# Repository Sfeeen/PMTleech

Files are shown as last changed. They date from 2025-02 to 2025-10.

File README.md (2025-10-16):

# 🚀 PMT Leech
#### A Parallel Memory Transactions Monitor

<p align="center">
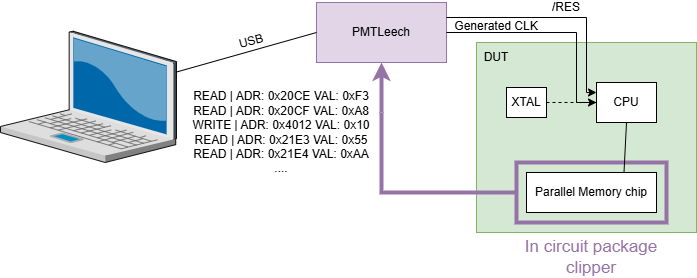
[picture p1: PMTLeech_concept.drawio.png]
PMT Leech Concept PMT Leech PCB
  
</p>

**PMT Leech** is a hardware + software tool that lets you monitor live memory accesses from a CPU to an external parallel memory chip.  
It streams transactions in real-time, while giving you full control over the system clock — allowing **pausing, stepping, and instruction-level debugging**.

---

## 🔧 When Should You Use PMT Leech?

PMT Leech is especially useful when working with **older electronic systems** that meet these two conditions:
- ✅ The system uses a **parallel memory chip** (like SRAM or EPROM)
- ✅ The CPU operates with an **external clock input**

---

## ⚙️ How It Works

By attaching PMT Leech to your memory chip (via clipper) and supplying your own clock signal to the CPU:
- You gain **live streaming** of memory transactions
- You can **pause or step** through firmware execution  
- You can **reverse engineer or debug** embedded firmware in a safe, controlled way

---

## 🧰 Hardware Overview

<p float="left">
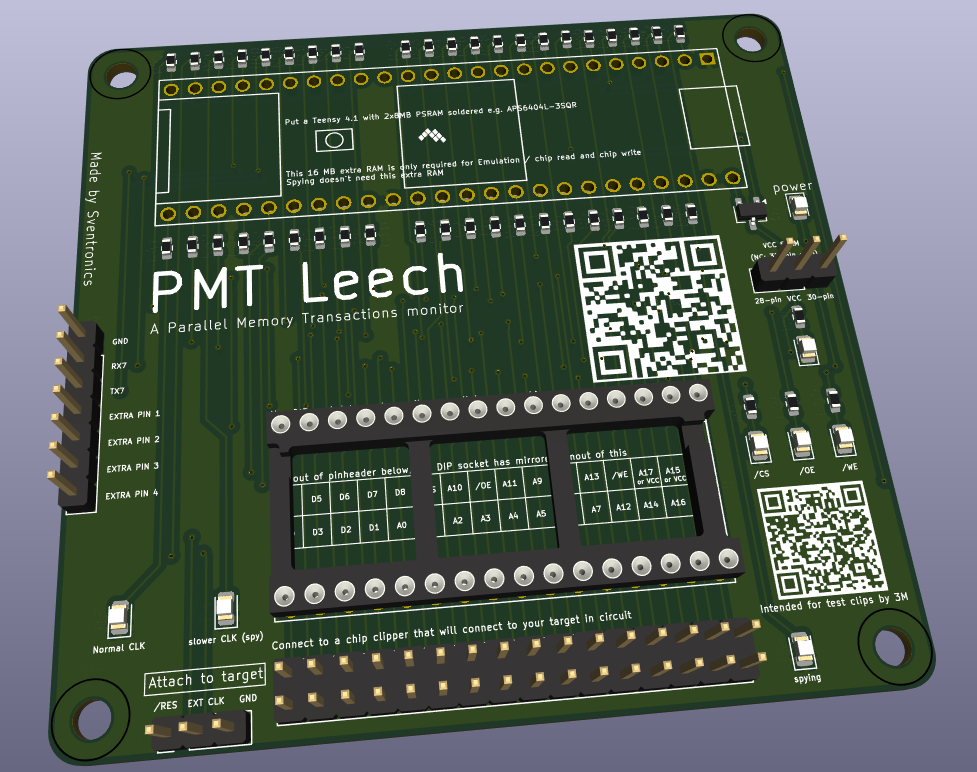
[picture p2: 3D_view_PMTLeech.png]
PMT Leech PCB
  
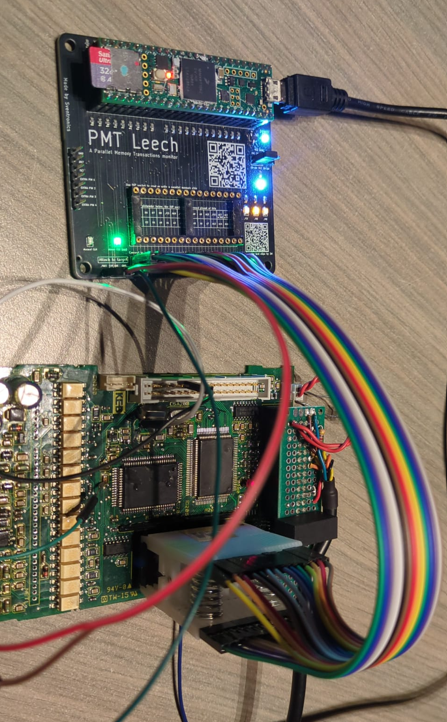
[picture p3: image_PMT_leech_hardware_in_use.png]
PMT Leech In Use In Use
  
</p>

---

## 🖥️ Software Features

<p align="center">
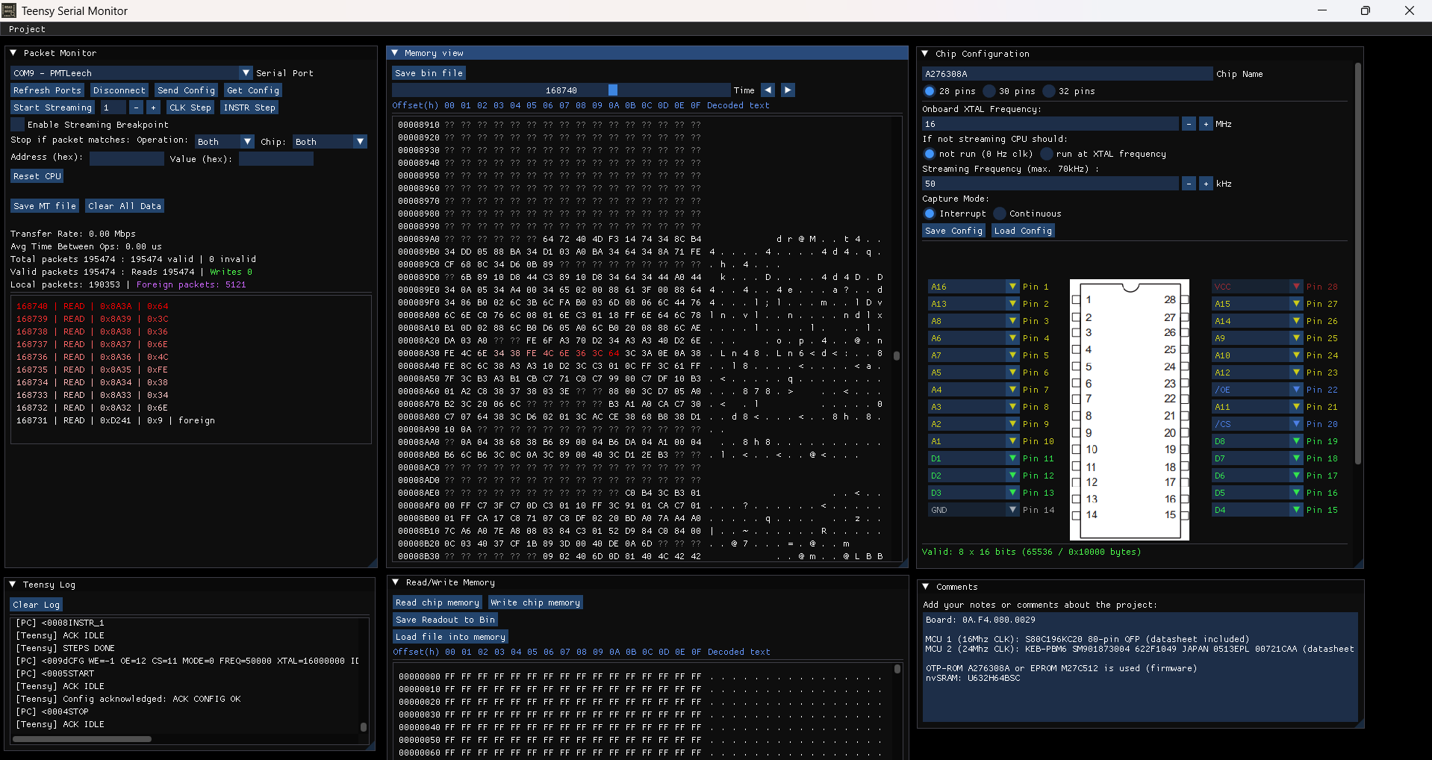
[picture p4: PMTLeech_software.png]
PMT Leech Software Software UI
  
</p>

- 🧩 Configurable pinout: Supports 28, 30, or 32-pin chips
- 📡 Live recording of transactions (up to 70kHz)
- 🎨 Interactive memory viewer with color-coded highlights
- ⏱ Step by **clock** or **instruction**
- 🧠 Detect and label **foreign packets** (from other devices on the memory bus)
- 💾 Off-circuit memory read/write with chip socket

---

## 🎞️ Demo

<p align="center">
  Demo Animation PMT Leech Demo
</p>

---

## 📋 Requirements

### ✅ Memory Chip
- Parallel bus
- ≤ 8-bit data
- ≤ 18 address lines
- 5V compatible (or use 330Ω series resistors)

### ✅ CPU
- Must allow external clock input
- 5V compatible (or 330Ω resistors)

### ⚠️ Note on Timing
The CPU will be **underclocked** (e.g., 8 MHz → 50 kHz). This may affect peripherals like UART:
- Ex: 9600 baud becomes ~60 baud — comms may break.

---

## 🧲 In-Circuit Clip Options

- [📄 3M Test Clip Brochure (PDF)](research/in%20circuit%20connection%20to%20chips/Test%20Clip%20Brochure%203M.pdf)

<p float="left">
  3M Clips
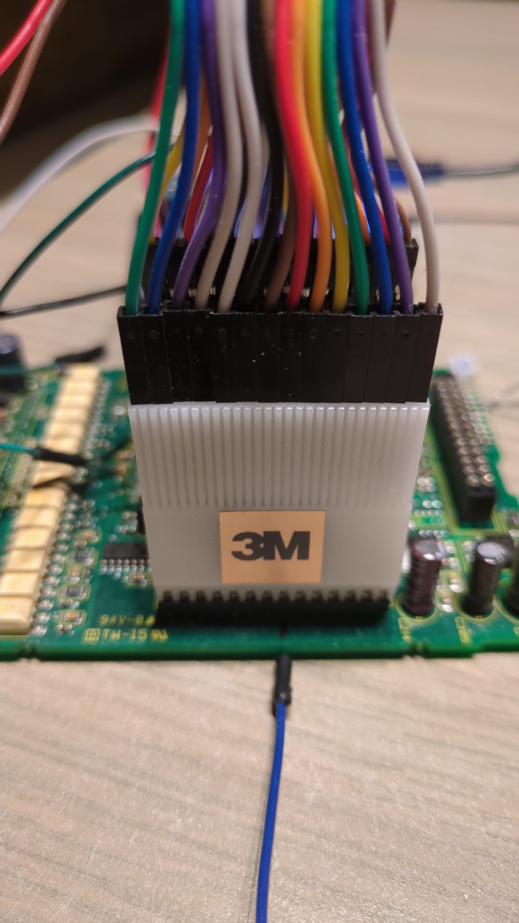
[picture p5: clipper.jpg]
Clipper Photo
  
</p>

---

## 🧠 Supported Memory Types

- EEPROM
- EPROM
- SRAM — **especially valuable** for volatile firmware systems

💡 Many older systems used **SRAM for firmware** due to speed advantages. PMT Leech lets you read these **volatile** setups **without desoldering**.

---

## 🔍 Example Use Cases

- **Bypass password protection**: Record firmware transactions during password validation and discover comparison logic or values.
- **Firmware reverse engineering**: Step through opcode streams and infer instruction flow.
- **Brownout glitching**: Control timing to inject faults and analyze behavior.
  - Related project: [Siemens Advanced Operator Panel](https://github.com/Sfeeen/Siemens-Advanced-Operator-Panel)

---

## 🛠️ Hardware Revisions

### PMT Leech v2 (Current)
<p align="center">
  PMT Leech v2
</p>

### PMT Leech v1 (Development Stage)
<p align="center">
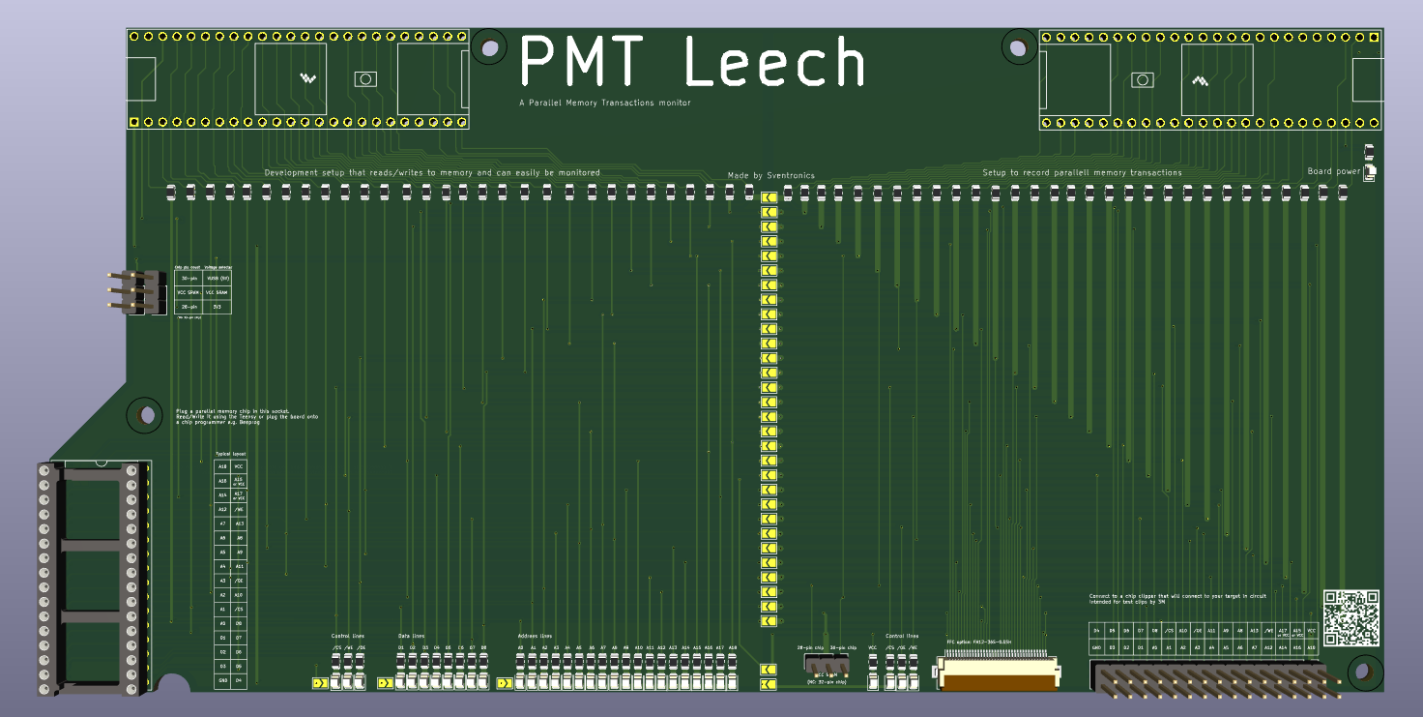
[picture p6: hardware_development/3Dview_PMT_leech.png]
PMT Leech v1
  
</p>

---

##

📧 **Contact**: `svenonderbeke [at] hotmail [dot] com`  
More info to be added soon.

---

### ☕ Support

If you’d like to support the development of PMT Leech, you can donate via Ko-fi:


## 🧪 Version

**Current Version:** `PMT Leech v2`

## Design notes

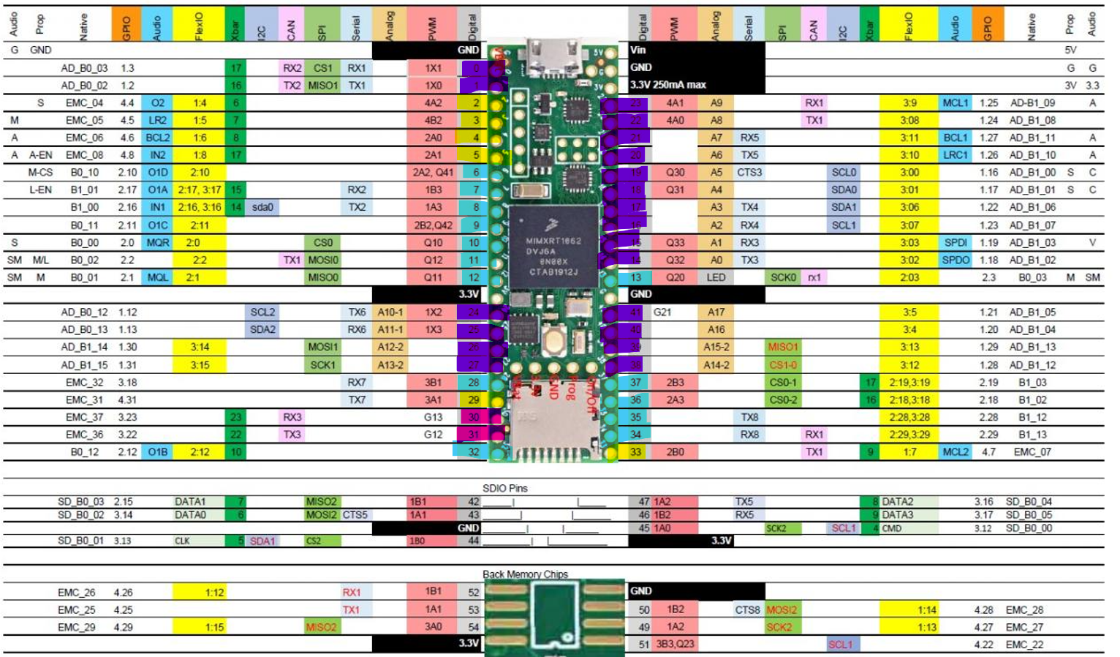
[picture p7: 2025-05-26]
hardware_development/gpio_teensy41_colored.png

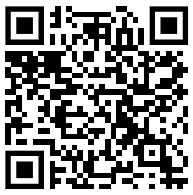
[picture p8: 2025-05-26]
hardware_development/clippers_QR.png

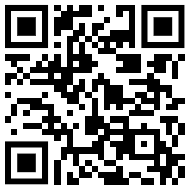
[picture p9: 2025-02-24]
hardware_development/github_PMTleech.png

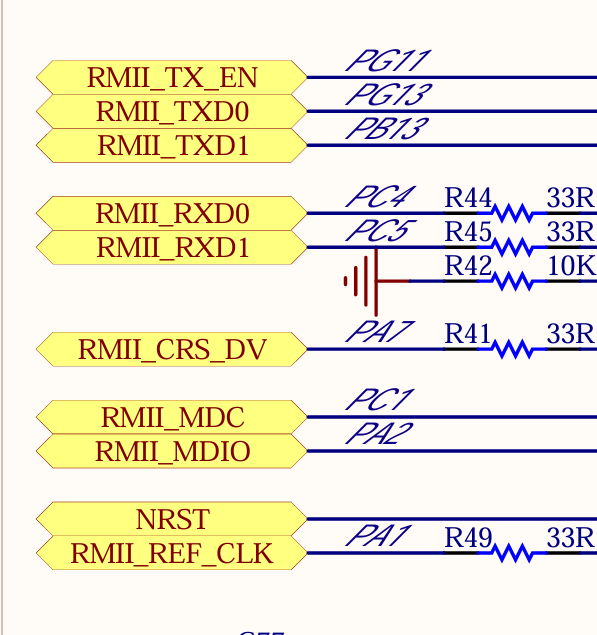
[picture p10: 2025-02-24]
research/stm32 approach w ethernet/nucLEO-H723ZG/RMII_pinout.png

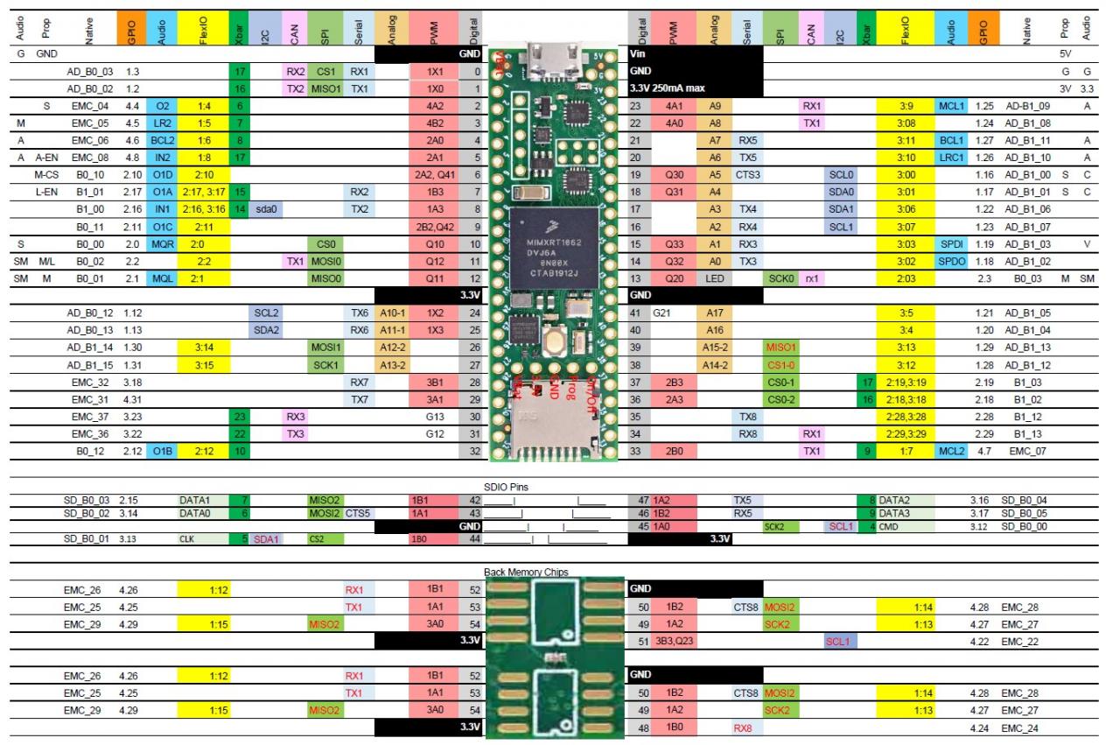
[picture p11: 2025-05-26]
hardware_development/T4.1-Cardlike.jpg

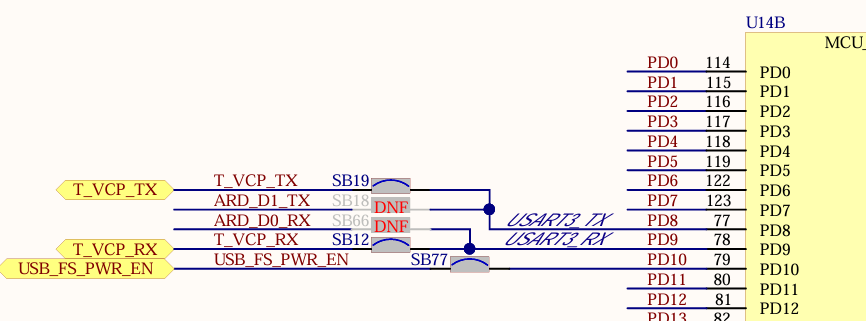
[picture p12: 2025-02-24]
research/stm32 approach w ethernet/nucLEO-H723ZG/USART3.png

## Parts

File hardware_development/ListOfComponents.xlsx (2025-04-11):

Category | Total segment price (€)
Electronic components | 20.96
Electronic units | 59.50
Connectors | 0.00
PCB and casing | 29.19
Mounting | 0.00
Total price | 109.64
Electronic components (ICs, resistors, capacitors, diodes, ...) |  |  |  |  |  |  | Electronic units (Micro-controllers, displays, ...) |  |  |  |  |  |  | Connectors/Large components |  |  |  |  |  |  | PCB and casing |  |  |  |  |  |  | Mounting (Screws, standoffs, spacers, ...)
Component Description | Mfr. Nr | Supplier No. | Supplier | Unit Price | Quantity | Total Price | Component Description | Mfr. Nr | Supplier No. | Supplier | Unit Price | Quantity | Total Price | Component Description | Mfr. Nr | Supplier No. | Supplier | Unit Price | Quantity | Total Price | Component Description | Mfr. Nr | Supplier No. | Supplier | Unit Price | Quantity | Total Price | Component Description | Mfr. Nr | Supplier No. | Supplier | Unit Price | Quantity | Total Price
Total segment price |  |  |  |  |  | 20.96 | Total segment price |  |  |  |  |  | 59.50 | Total segment price |  |  |  |  |  | 0.00 | Total segment price |  |  |  |  |  | 29.19 | Total segment price |  |  |  |  |  | 0.00
TXB0108PWR level shifter | TXB0108PWR | 595-TXB0108PWR | Mouser | 0.89 | 10 | 8.85 | Teensy 4.1 | Teensy 4.1 | 002700 | TINYTRONICS | 29.75 | 2 | 59.50 |  |  |  |  |  |  | 0.00 | PMT Leech PCB 5 stuks | W202502242057287 | W202502242057287 | JLCPCB | 29.19 | 1 | 29.19 |  |  |  |  |  |  | 0.00
330R 0805 weerstand | CRCW0805330RJNEAHP | 71-CRCW0805330RJNEAH | Mouser | 0.04 | 100 | 3.90 |  |  |  |  |  |  | 0.00 |  |  |  |  |  |  | 0.00 |  |  |  |  |  |  | 0.00 |  |  |  |  |  |  | 0.00
LEDS 0805 | 150080BS75000 | 2322075 | Farnell | 0.18 | 35 | 6.47 |  |  |  |  |  |  | 0.00 |  |  |  |  |  |  | 0.00 |  |  |  |  |  |  | 0.00 |  |  |  |  |  |  | 0.00
teensy koelvin | HSB03-121218 | 490-HSB03-121218 | Mouser | 0.86 | 2 | 1.73 |  |  |  |  |  |  | 0.00 |  |  |  |  |  |  | 0.00 |  |  |  |  |  |  | 0.00 |  |  |  |  |  |  | 0.00
IC voet lange poten | t2AJ1401 | t2AJ1401 | esengo |  |  | 0.00 |  |  |  |  |  |  | 0.00 |  |  |  |  |  |  | 0.00 |  |  |  |  |  |  | 0.00 |  |  |  |  |  |  | 0.00
 |  |  |  |  |  | 0.00 |  |  |  |  |  |  | 0.00 |  |  |  |  |  |  | 0.00 |  |  |  |  |  |  | 0.00 |  |  |  |  |  |  | 0.00
 |  |  |  |  |  | 0.00 |  |  |  |  |  |  | 0.00 |  |  |  |  |  |  | 0.00 |  |  |  |  |  |  | 0.00 |  |  |  |  |  |  | 0.00
 |  |  |  |  |  | 0.00 |  |  |  |  |  |  | 0.00 |  |  |  |  |  |  | 0.00 |  |  |  |  |  |  | 0.00 |  |  |  |  |  |  | 0.00
 |  |  |  |  |  | 0.00 |  |  |  |  |  |  | 0.00 |  |  |  |  |  |  | 0.00 |  |  |  |  |  |  | 0.00 |  |  |  |  |  |  | 0.00
 |  |  |  |  |  | 0.00 |  |  |  |  |  |  | 0.00 |  |  |  |  |  |  | 0.00 |  |  |  |  |  |  | 0.00 |  |  |  |  |  |  | 0.00
 |  |  |  |  |  | 0.00 |  |  |  |  |  |  | 0.00 |  |  |  |  |  |  | 0.00 |  |  |  |  |  |  | 0.00 |  |  |  |  |  |  | 0.00
 |  |  |  |  |  | 0.00 |  |  |  |  |  |  | 0.00 |  |  |  |  |  |  | 0.00 |  |  |  |  |  |  | 0.00 |  |  |  |  |  |  | 0.00
 |  |  |  |  |  | 0.00 |  |  |  |  |  |  | 0.00 |  |  |  |  |  |  | 0.00 |  |  |  |  |  |  | 0.00 |  |  |  |  |  |  | 0.00
 |  |  |  |  |  | 0.00 |  |  |  |  |  |  | 0.00 |  |  |  |  |  |  | 0.00 |  |  |  |  |  |  | 0.00 |  |  |  |  |  |  | 0.00
 |  |  |  |  |  | 0.00 |  |  |  |  |  |  | 0.00 |  |  |  |  |  |  | 0.00 |  |  |  |  |  |  | 0.00 |  |  |  |  |  |  | 0.00
 |  |  |  |  |  | 0.00 |  |  |  |  |  |  | 0.00 |  |  |  |  |  |  | 0.00 |  |  |  |  |  |  | 0.00 |  |  |  |  |  |  | 0.00
 |  |  |  |  |  | 0.00 |  |  |  |  |  |  | 0.00 |  |  |  |  |  |  | 0.00 |  |  |  |  |  |  | 0.00 |  |  |  |  |  |  | 0.00
 |  |  |  |  |  | 0.00 |  |  |  |  |  |  | 0.00 |  |  |  |  |  |  | 0.00 |  |  |  |  |  |  | 0.00 |  |  |  |  |  |  | 0.00
 |  |  |  |  |  | 0.00 |  |  |  |  |  |  | 0.00 |  |  |  |  |  |  | 0.00 |  |  |  |  |  |  | 0.00 |  |  |  |  |  |  | 0.00
 |  |  |  |  |  | 0.00 |  |  |  |  |  |  | 0.00 |  |  |  |  |  |  | 0.00 |  |  |  |  |  |  | 0.00 |  |  |  |  |  |  | 0.00
 |  |  |  |  |  | 0.00 |  |  |  |  |  |  | 0.00 |  |  |  |  |  |  | 0.00 |  |  |  |  |  |  | 0.00 |  |  |  |  |  |  | 0.00
 |  |  |  |  |  | 0.00 |  |  |  |  |  |  | 0.00 |  |  |  |  |  |  | 0.00 |  |  |  |  |  |  | 0.00 |  |  |  |  |  |  | 0.00
 |  |  |  |  |  | 0.00 |  |  |  |  |  |  | 0.00 |  |  |  |  |  |  | 0.00 |  |  |  |  |  |  | 0.00 |  |  |  |  |  |  | 0.00
 |  |  |  |  |  | 0.00 |  |  |  |  |  |  | 0.00 |  |  |  |  |  |  | 0.00 |  |  |  |  |  |  | 0.00 |  |  |  |  |  |  | 0.00
 |  |  |  |  |  | 0.00 |  |  |  |  |  |  | 0.00 |  |  |  |  |  |  | 0.00 |  |  |  |  |  |  | 0.00 |  |  |  |  |  |  | 0.00
 |  |  |  |  |  | 0.00 |  |  |  |  |  |  | 0.00 |  |  |  |  |  |  | 0.00 |  |  |  |  |  |  | 0.00 |  |  |  |  |  |  | 0.00
 |  |  |  |  |  | 0.00 |  |  |  |  |  |  | 0.00 |  |  |  |  |  |  | 0.00 |  |  |  |  |  |  | 0.00 |  |  |  |  |  |  | 0.00
 |  |  |  |  |  | 0.00 |  |  |  |  |  |  | 0.00 |  |  |  |  |  |  | 0.00 |  |  |  |  |  |  | 0.00 |  |  |  |  |  |  | 0.00
 |  |  |  |  |  | 0.00 |  |  |  |  |  |  | 0.00 |  |  |  |  |  |  | 0.00 |  |  |  |  |  |  | 0.00 |  |  |  |  |  |  | 0.00
 |  |  |  |  |  | 0.00 |  |  |  |  |  |  | 0.00 |  |  |  |  |  |  | 0.00 |  |  |  |  |  |  | 0.00 |  |  |  |  |  |  | 0.00
 |  |  |  |  |  | 0.00
 |  |  |  |  |  | 0.00
 |  |  |  |  |  | 0.00
 |  |  |  |  |  | 0.00
 |  |  |  |  |  | 0.00
 |  |  |  |  |  | 0.00
 |  |  |  |  |  | 0.00
 |  |  |  |  |  | 0.00
 |  |  |  |  |  | 0.00
 |  |  |  |  |  | 0.00
 |  |  |  |  |  | 0.00
 |  |  |  |  |  | 0.00
 |  |  |  |  |  | 0.00

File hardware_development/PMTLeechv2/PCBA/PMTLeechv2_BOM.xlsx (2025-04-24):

Id | Designator | Footprint | Quantity | Designation | Supplier and ref
1 | R30,R99,R98,R97,R96,R95,R43,R42,R41,R40,R39,R38,R37,R36,R35,R34,R32,R31,R29,R28,R27,R26,R25,R24,R23,R22,R21,R20,R19,R18,R17,R16,R15,R14,R13,R12,R11,R10,R9,R8,R7,R6,R5,R4,R3,R2,R1 | R_0603_1608Metric | 47 | 330R
6 | D34,D35,D33 | LED_0805_2012Metric | 3 | LED
7 | D32,D31 | LED_0805_2012Metric | 2 | LED
8 | D1 | LED_0805_2012Metric | 1 | LED
9 | D2 | LED_0805_2012Metric | 1 | LED
10 | D3 | LED_0805_2012Metric | 1 | LED

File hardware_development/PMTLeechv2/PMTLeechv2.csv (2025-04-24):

Id | Designator | Footprint | Quantity | Designation | Supplier and ref
1 | R30,R99,R98,R97,R96,R95,R43,R42,R41,R40,R39,R38,R37,R36,R35,R34,R32,R31,R29,R28,R27,R26,R25,R24,R23,R22,R21,R20,R19,R18,R17,R16,R15,R14,R13,R12,R11,R10,R9,R8,R7,R6,R5,R4,R3,R2,R1 | R_0603_1608Metric | 47 | 330R
2 | Q2 | TSOT-23 | 1 | Q_PMOS_GSD
3 | J5 | DIP-32_W15.24mm_Socket_LongPads | 1 | Conn_02x16_Counter_Clockwise
4 | J3 | PinHeader_1x07_P2.54mm_Vertical | 1 | Conn_01x07
5 | J1,J2 | PinHeader_1x03_P2.54mm_Vertical | 2 | Conn_01x03
6 | D3,D1,D2,D33,D32,D34,D35,D31 | LED_0805_2012Metric | 8 | LED
7 | U1 | Teensy41 | 1 | Teensy4.1
8 | J8 | PinHeader_2x16_P2.54mm_Vertical_clockwise | 1 | Conn_02x16_Counter_Clockwise

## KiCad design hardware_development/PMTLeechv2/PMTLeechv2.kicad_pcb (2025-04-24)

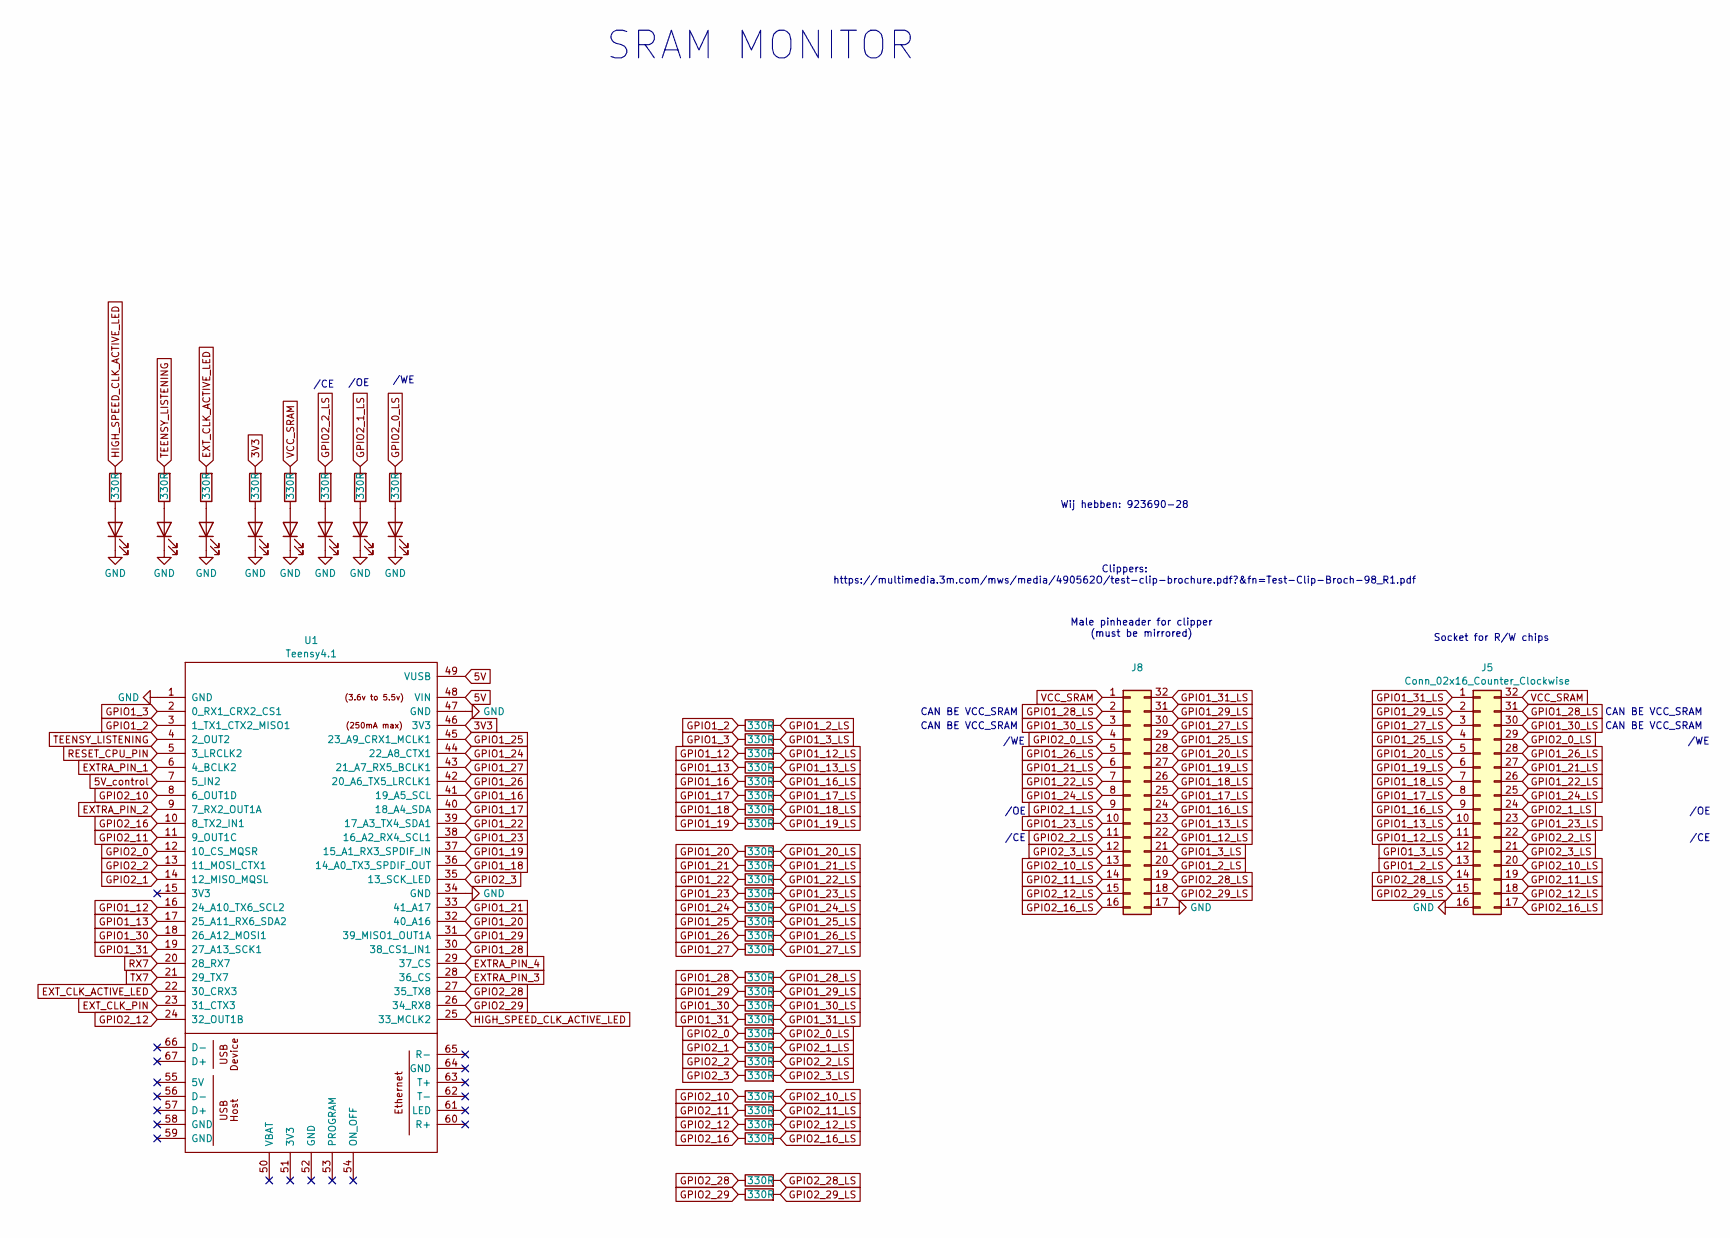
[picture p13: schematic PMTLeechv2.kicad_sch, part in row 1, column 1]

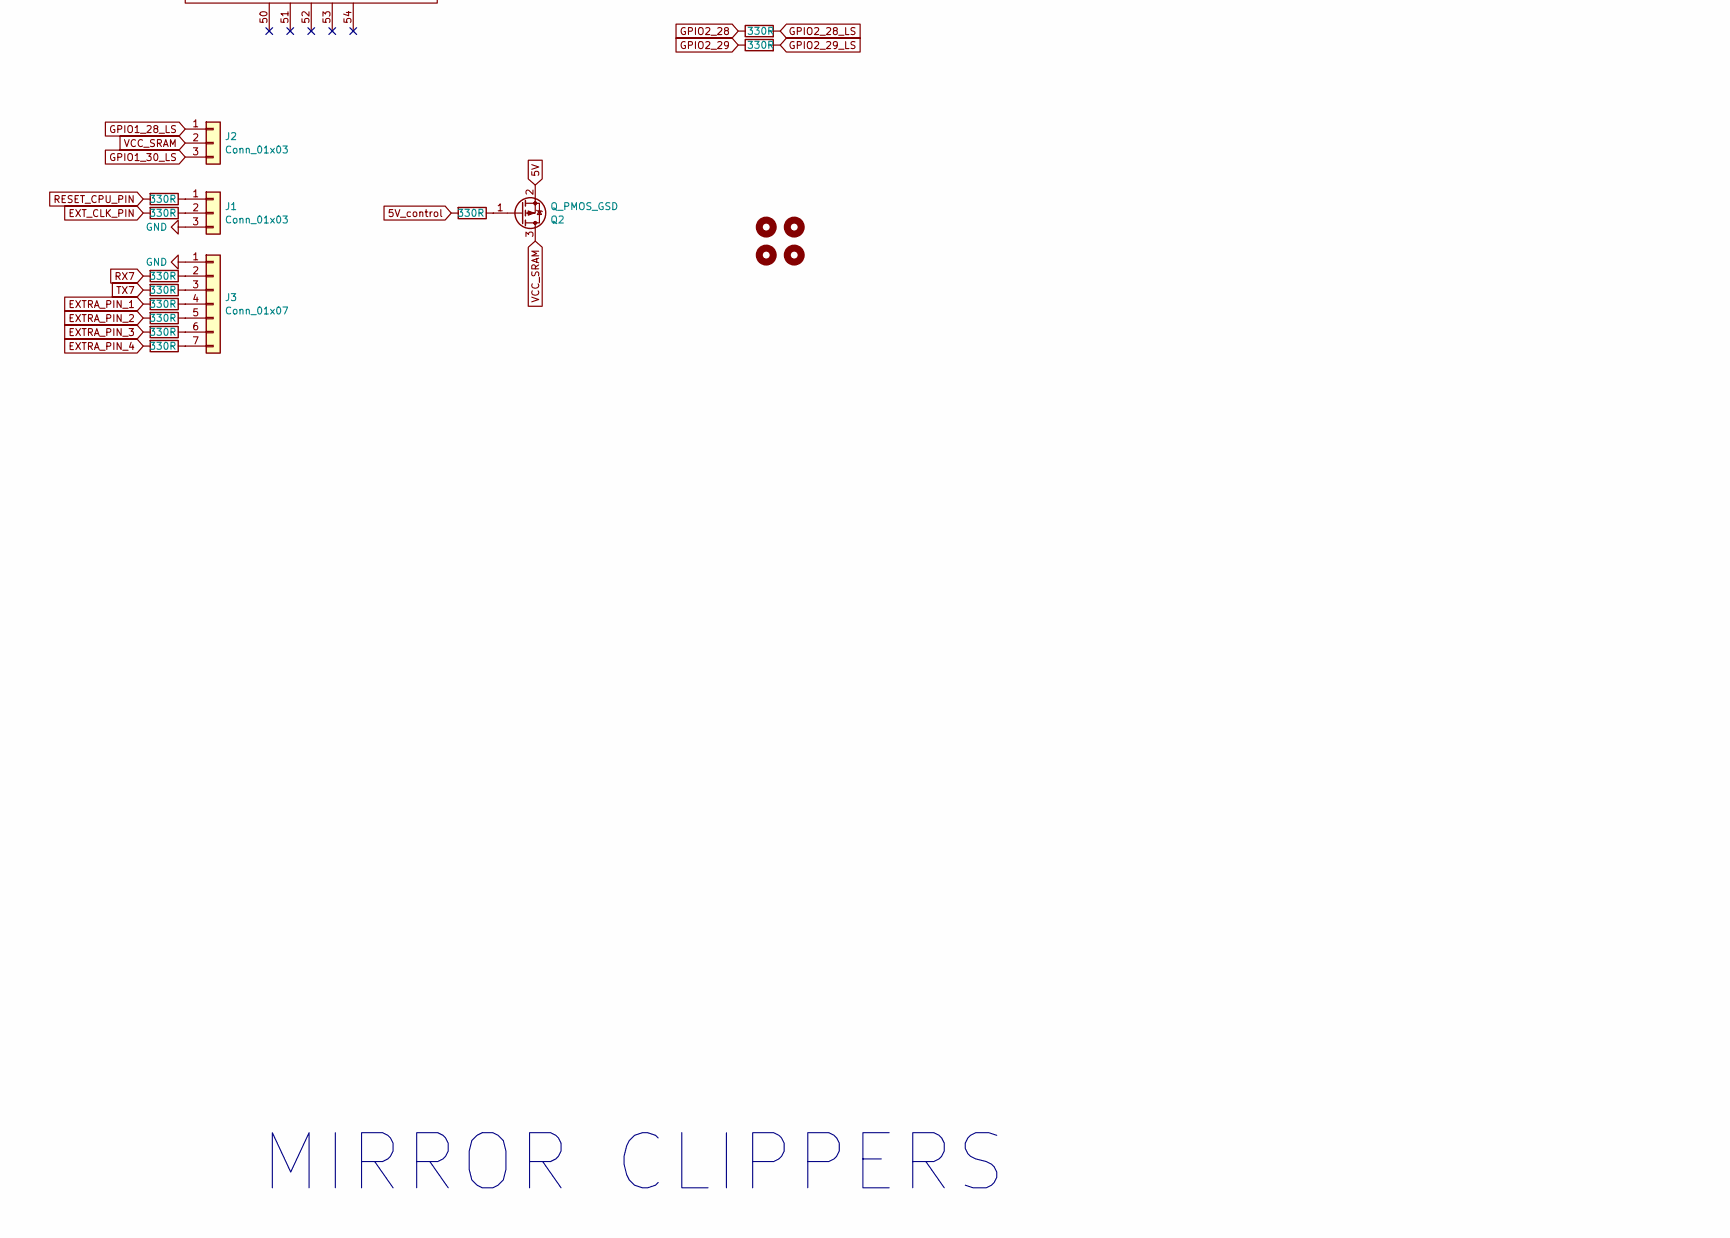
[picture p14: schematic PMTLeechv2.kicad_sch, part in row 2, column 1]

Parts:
D1, D2, D3, D31, D32, D33, D34, D35: LED; LED_0805_2012Metric
H1, H2, H3, H4: MountingHole; MountingHole_3.2mm_M3
J1, J2: Conn_01x03; PinHeader_1x03_P2.54mm_Vertical
J3: Conn_01x07; PinHeader_1x07_P2.54mm_Vertical
J5: Conn_02x16_Counter_Clockwise; DIP-32_W15.24mm_Socket_LongPads
J8: Conn_02x16_Counter_Clockwise; PinHeader_2x16_P2.54mm_Vertical_clockwise
Q2: Q_PMOS_GSD; TSOT-23
R1, R2, R3, R4, R5, R6, R7, R8, R9, R10, R11, R12, R13, R14, R15, R16, R17, R18, R19, R20, R21, R22, R23, R24, R25, R26, R27, R28, R29, R30, R31, R32, R34, R35, R36, R37, R38, R39, R40, R41, R42, R43, R95, R96, R97, R98, R99: 330R; R_0603_1608Metric
U1: Teensy4.1; Teensy41

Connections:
3V3: R95.2, U1.46 (3V3)
5V: Q2.2 (S), U1.48 (VIN), U1.49 (VUSB)
5V_control: R30.2, U1.7 (5_IN2)
EXTRA_PIN_1: R37.2, U1.6 (4_BCLK2)
EXTRA_PIN_2: R42.2, U1.9 (7_RX2_OUT1A)
EXTRA_PIN_3: R38.2, U1.28 (36_CS)
EXTRA_PIN_4: R43.2, U1.29 (37_CS)
EXT_CLK_ACTIVE_LED: R34.2, U1.22 (30_CRX3)
EXT_CLK_PIN: R29.2, U1.23 (31_CTX3)
GND: D1.1 (K), D2.1 (K), D3.1 (K), D31.1 (K), D32.1 (K), D33.1 (K), D34.1 (K), D35.1 (K), J1.3, J3.1, J5.16, J8.17, U1.1 (GND), U1.34 (GND), U1.47 (GND)
GPIO1_2: R1.1, U1.3 (1_TX1_CTX2_MISO1)
GPIO1_2_LS: J5.13, J8.20, R1.2
GPIO1_3: R2.1, U1.2 (0_RX1_CRX2_CS1)
GPIO1_3_LS: J5.12, J8.21, R2.2
GPIO1_12: R3.1, U1.16 (24_A10_TX6_SCL2)
GPIO1_12_LS: J5.11, J8.22, R3.2
GPIO1_13: R4.1, U1.17 (25_A11_RX6_SDA2)
GPIO1_13_LS: J5.10, J8.23, R4.2
GPIO1_16: R5.1, U1.41 (19_A5_SCL)
GPIO1_16_LS: J5.9, J8.24, R5.2
GPIO1_17: R6.1, U1.40 (18_A4_SDA)
GPIO1_17_LS: J5.8, J8.25, R6.2
GPIO1_18: R7.1, U1.36 (14_A0_TX3_SPDIF_OUT)
GPIO1_18_LS: J5.7, J8.26, R7.2
GPIO1_19: R8.1, U1.37 (15_A1_RX3_SPDIF_IN)
GPIO1_19_LS: J5.6, J8.27, R8.2
GPIO1_20: R9.1, U1.32 (40_A16)
GPIO1_20_LS: J5.5, J8.28, R9.2
GPIO1_21: R10.1, U1.33 (41_A17)
GPIO1_21_LS: J5.27, J8.6, R10.2
GPIO1_22: R11.1, U1.39 (17_A3_TX4_SDA1)
GPIO1_22_LS: J5.26, J8.7, R11.2
GPIO1_23: R12.1, U1.38 (16_A2_RX4_SCL1)
GPIO1_23_LS: J5.23, J8.10, R12.2
GPIO1_24: R13.1, U1.44 (22_A8_CTX1)
GPIO1_24_LS: J5.25, J8.8, R13.2
GPIO1_25: R14.1, U1.45 (23_A9_CRX1_MCLK1)
GPIO1_25_LS: J5.4, J8.29, R14.2
GPIO1_26: R15.1, U1.42 (20_A6_TX5_LRCLK1)
GPIO1_26_LS: J5.28, J8.5, R15.2
GPIO1_27: R16.1, U1.43 (21_A7_RX5_BCLK1)
GPIO1_27_LS: J5.3, J8.30, R16.2
GPIO1_28: R17.1, U1.30 (38_CS1_IN1)
GPIO1_28_LS: J2.1, J5.31, J8.2, R17.2
GPIO1_29: R18.1, U1.31 (39_MISO1_OUT1A)
GPIO1_29_LS: J5.2, J8.31, R18.2
GPIO1_30: R19.1, U1.18 (26_A12_MOSI1)
GPIO1_30_LS: J2.3, J5.30, J8.3, R19.2
GPIO1_31: R20.1, U1.19 (27_A13_SCK1)
GPIO1_31_LS: J5.1, J8.32, R20.2
GPIO2_0: R21.1, U1.12 (10_CS_MQSR)
GPIO2_0_LS: J5.29, J8.4, R21.2, R99.2
GPIO2_1: R22.1, U1.14 (12_MISO_MQSL)
GPIO2_1_LS: J5.24, J8.9, R22.2, R98.2
GPIO2_2: R23.1, U1.13 (11_MOSI_CTX1)
GPIO2_2_LS: J5.22, J8.11, R23.2, R97.2
GPIO2_3: R24.1, U1.35 (13_SCK_LED)
GPIO2_3_LS: J5.21, J8.12, R24.2
GPIO2_10: R25.1, U1.8 (6_OUT1D)
GPIO2_10_LS: J5.20, J8.13, R25.2
GPIO2_11: R26.1, U1.11 (9_OUT1C)
GPIO2_11_LS: J5.19, J8.14, R26.2
GPIO2_12: R27.1, U1.24 (32_OUT1B)
GPIO2_12_LS: J5.18, J8.15, R27.2
GPIO2_16: R28.1, U1.10 (8_TX2_IN1)
GPIO2_16_LS: J5.17, J8.16, R28.2
GPIO2_28: R31.1, U1.27 (35_TX8)
GPIO2_28_LS: J5.14, J8.19, R31.2
GPIO2_29: R32.1, U1.26 (34_RX8)
GPIO2_29_LS: J5.15, J8.18, R32.2
HIGH_SPEED_CLK_ACTIVE_LED: R41.2, U1.25 (33_MCLK2)
unnamed: D1.2 (A), R34.1
unnamed: D2.2 (A), R35.1
unnamed: D3.2 (A), R41.1
unnamed: D31.2 (A), R95.1
unnamed: D32.2 (A), R96.1
unnamed: D33.2 (A), R97.1
unnamed: D34.2 (A), R98.1
unnamed: D35.2 (A), R99.1
unnamed: J1.1, R36.1
unnamed: J1.2, R29.1
unnamed: J3.2, R39.1
unnamed: J3.3, R40.1
unnamed: J3.4, R37.1
unnamed: J3.5, R42.1
unnamed: J3.6, R38.1
unnamed: J3.7, R43.1
unnamed: Q2.1 (G), R30.1
RESET_CPU_PIN: R36.2, U1.5 (3_LRCLK2)
RX7: R39.2, U1.20 (28_RX7)
TEENSY_LISTENING: R35.2, U1.4 (2_OUT2)
TX7: R40.2, U1.21 (29_TX7)
VCC_SRAM: J2.2, J5.32, J8.1, Q2.3 (D), R96.2

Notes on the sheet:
Wij hebben: 923690-28
CAN BE VCC_SRAM
/CE
/WE
SRAM MONITOR
MIRROR CLIPPERS
Clippers: https://multimedia.3m.com/mws/media/490562O/test-clip-brochure.pdf?&fn=Test-Clip-Broch-98_R1.pdf
Socket for R/W chips
/OE
Male pinheader for clipper (must be mirrored)

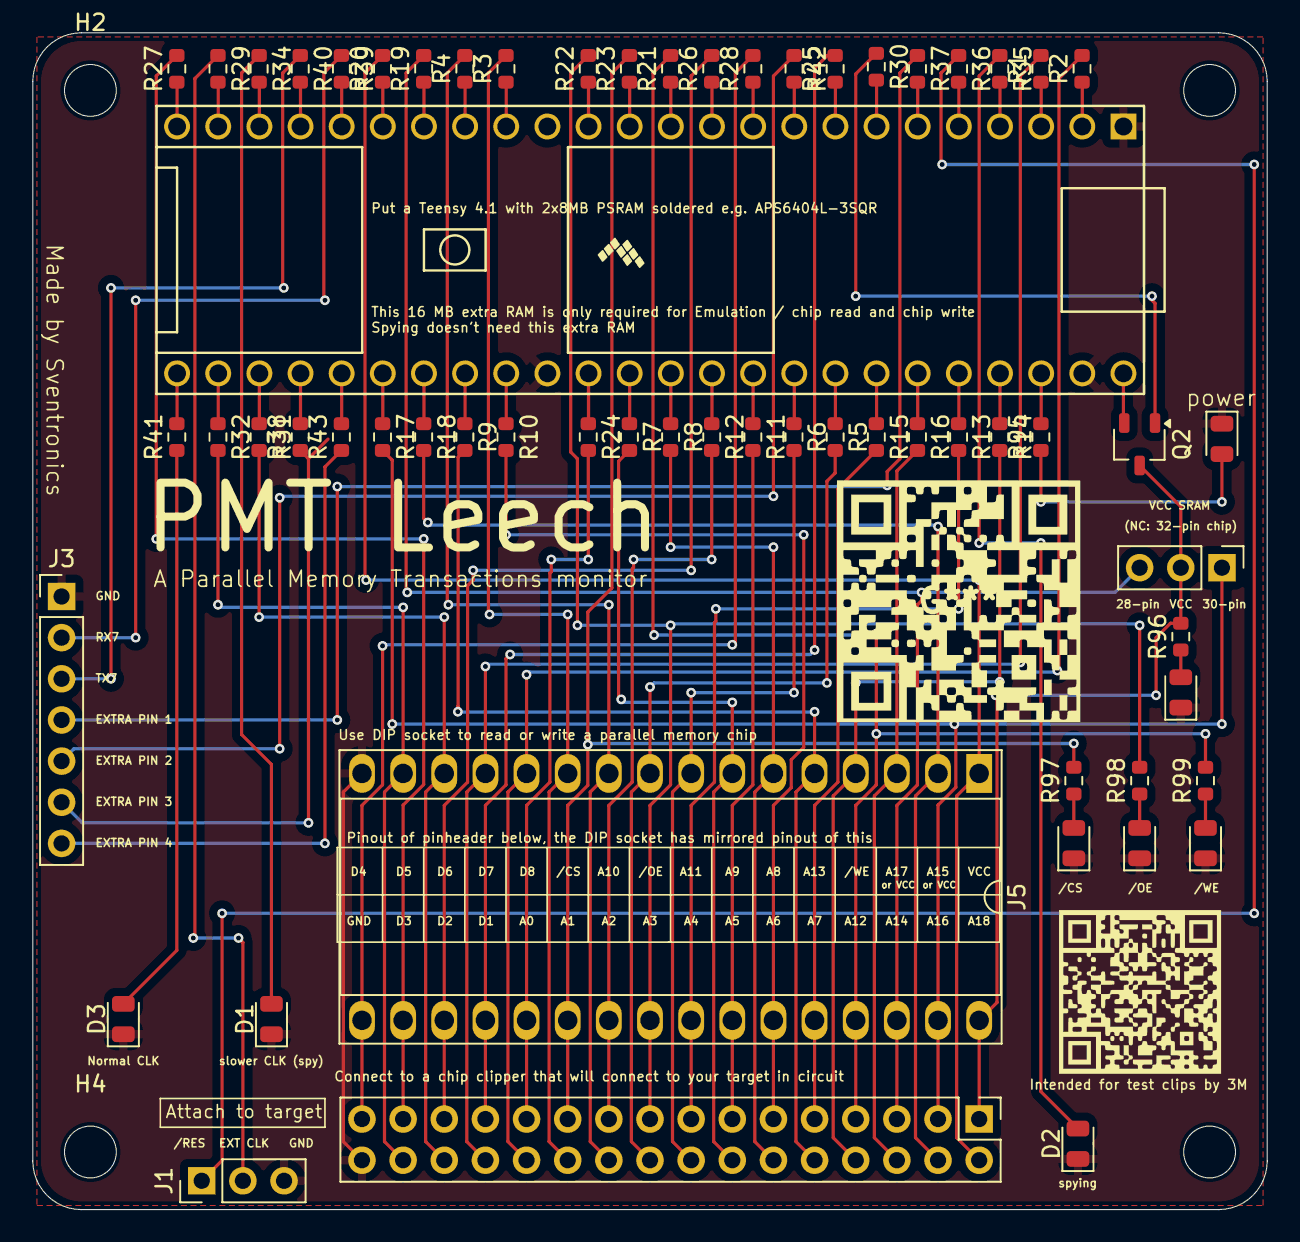
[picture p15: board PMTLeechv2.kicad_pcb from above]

Board: 2 copper layers, 76.2 x 72.6 mm, 66 parts (0 on the bottom side), 93 nets.

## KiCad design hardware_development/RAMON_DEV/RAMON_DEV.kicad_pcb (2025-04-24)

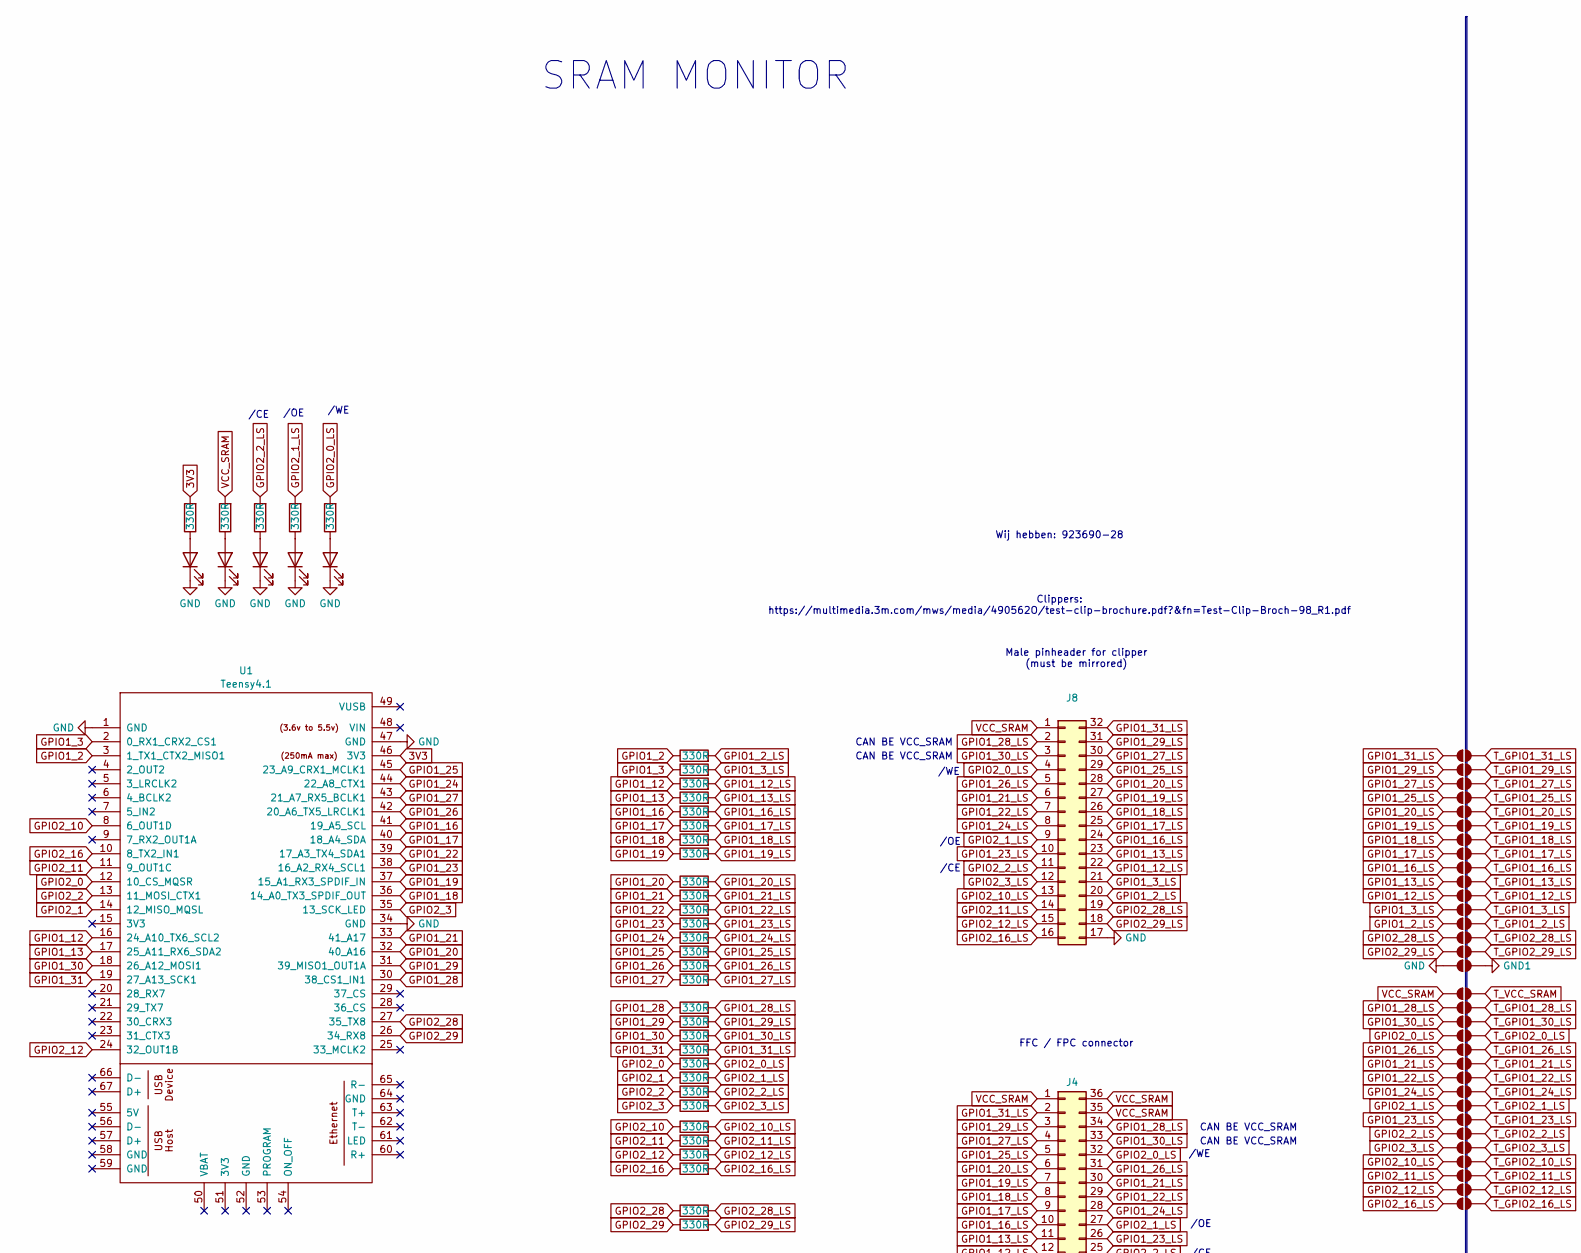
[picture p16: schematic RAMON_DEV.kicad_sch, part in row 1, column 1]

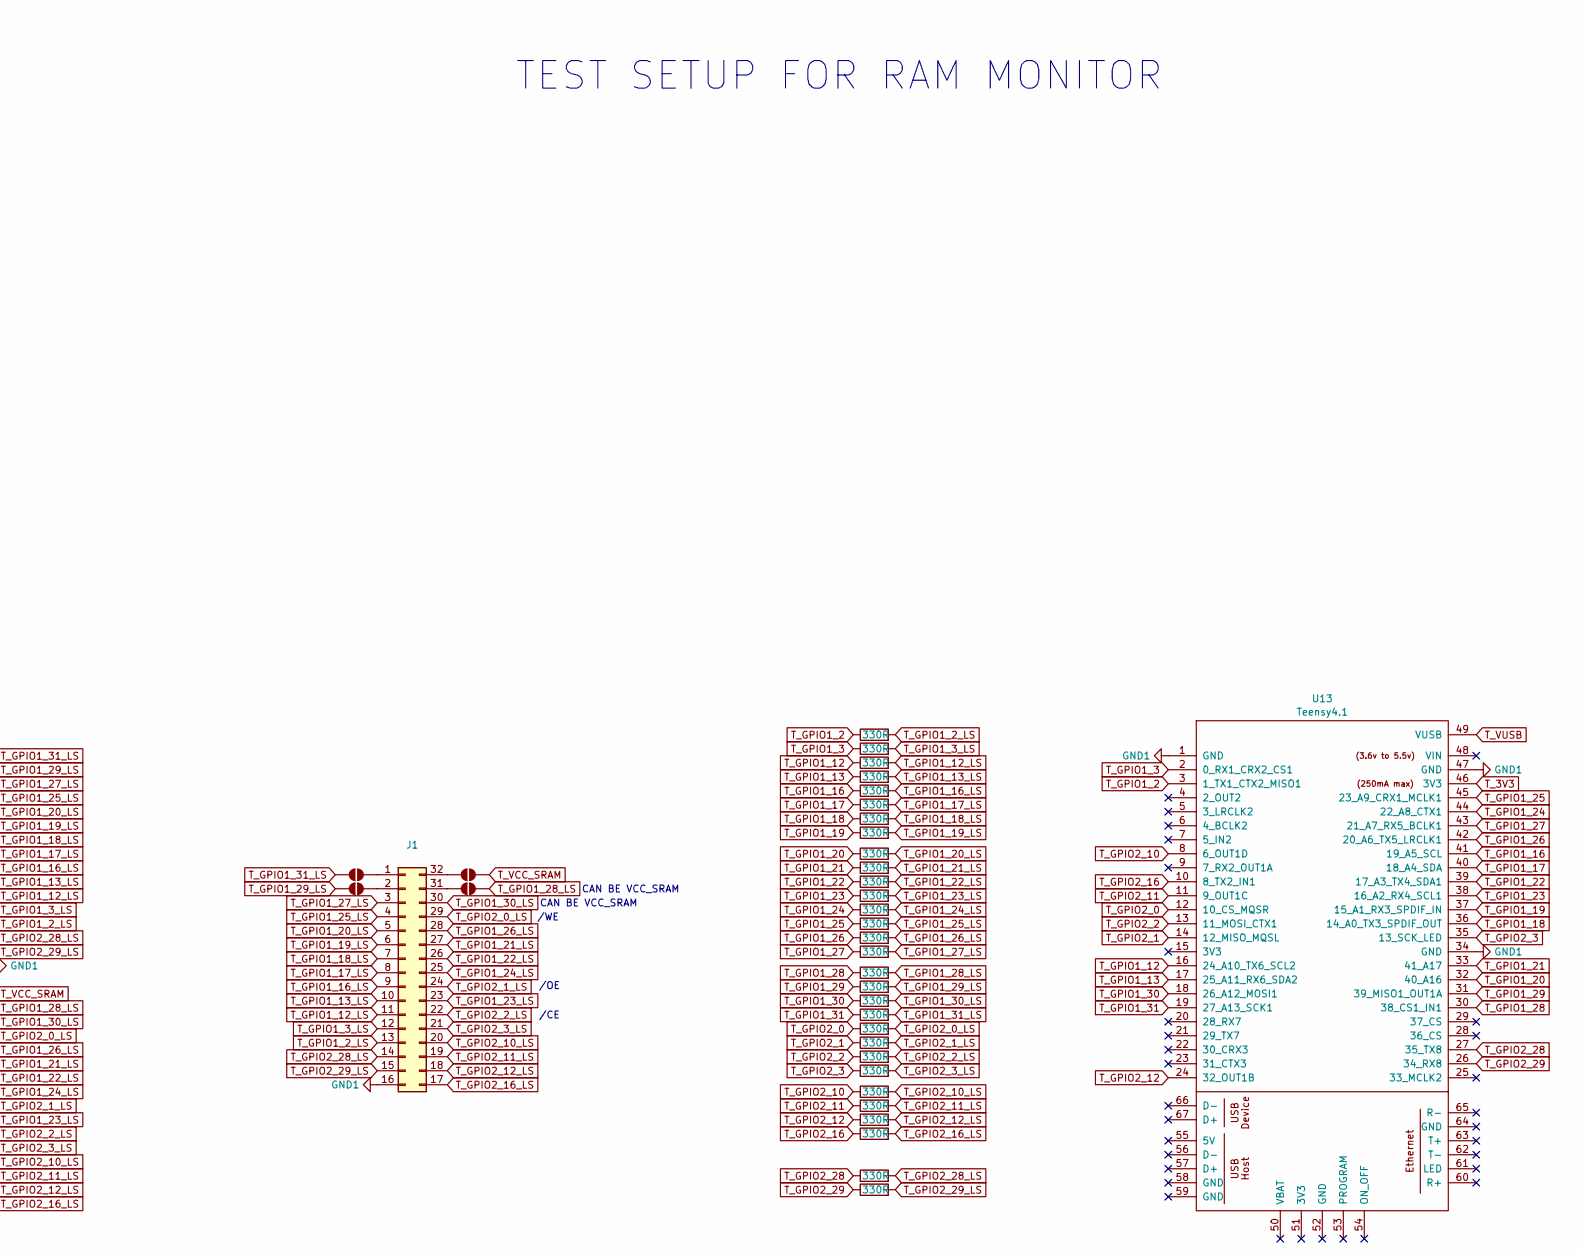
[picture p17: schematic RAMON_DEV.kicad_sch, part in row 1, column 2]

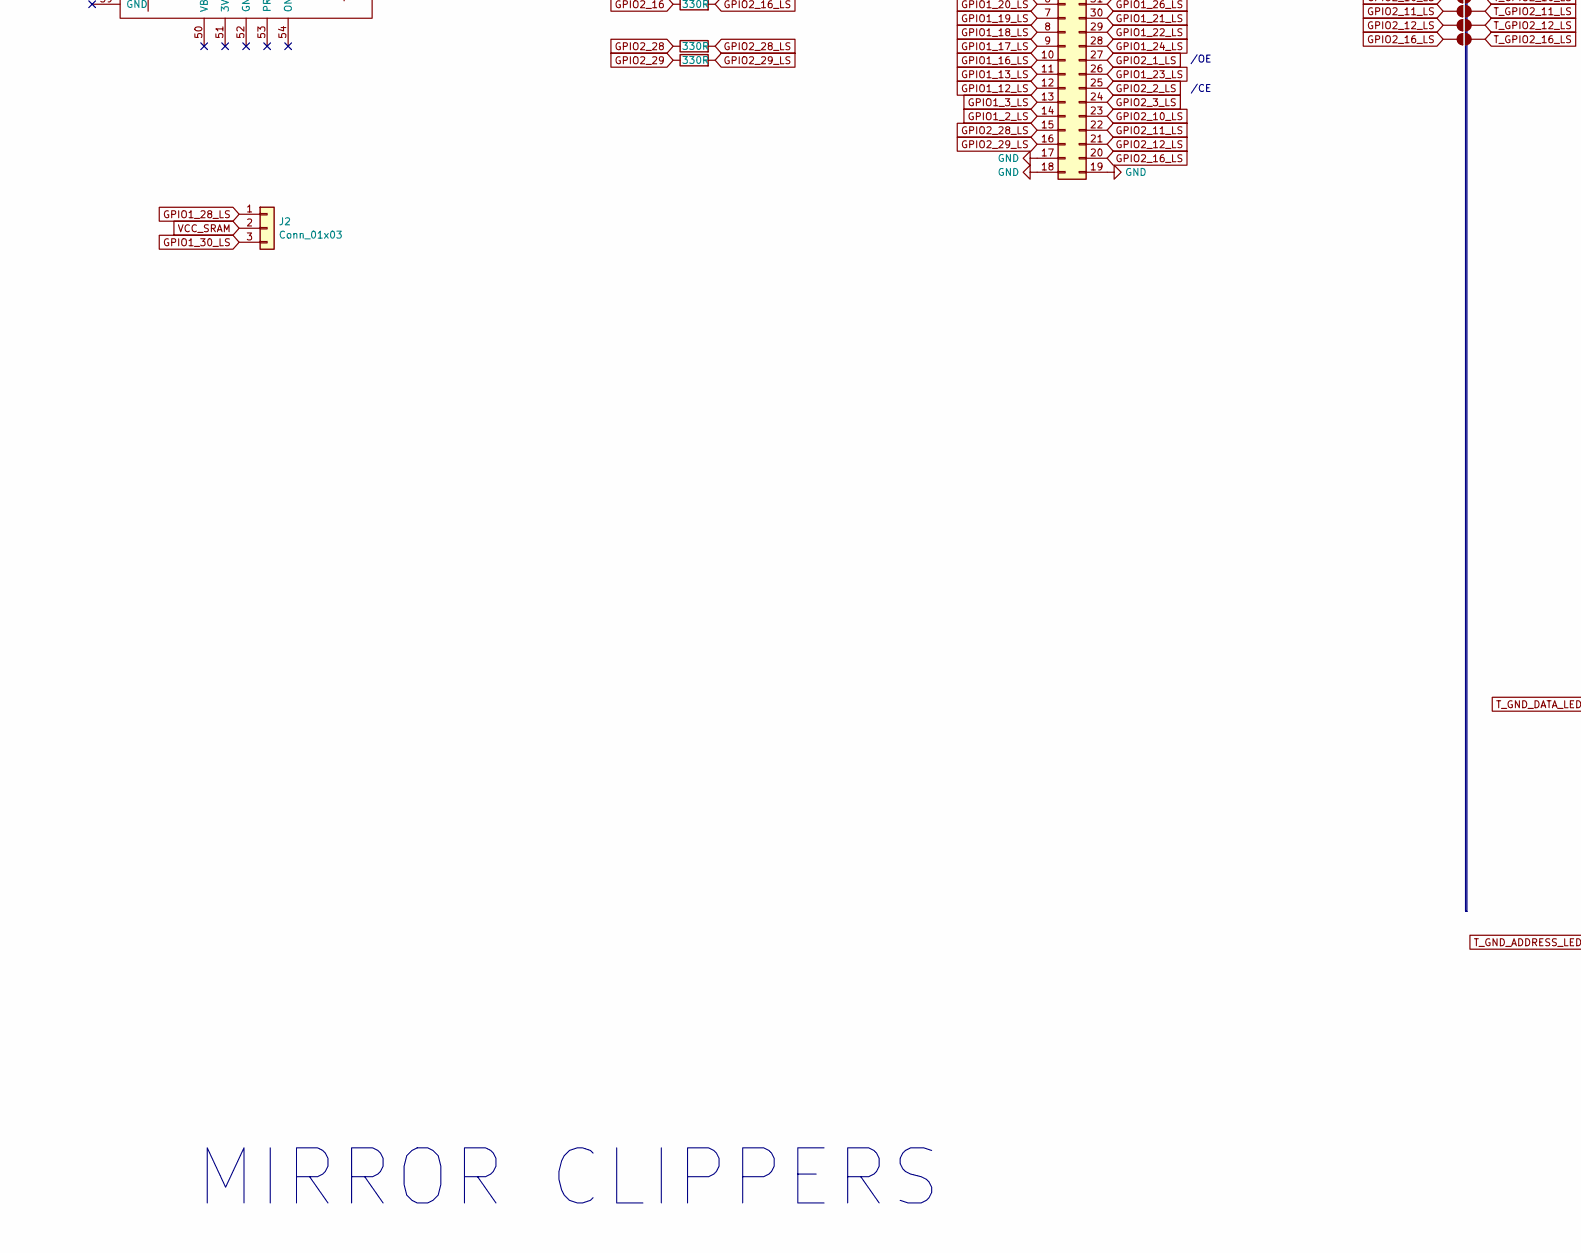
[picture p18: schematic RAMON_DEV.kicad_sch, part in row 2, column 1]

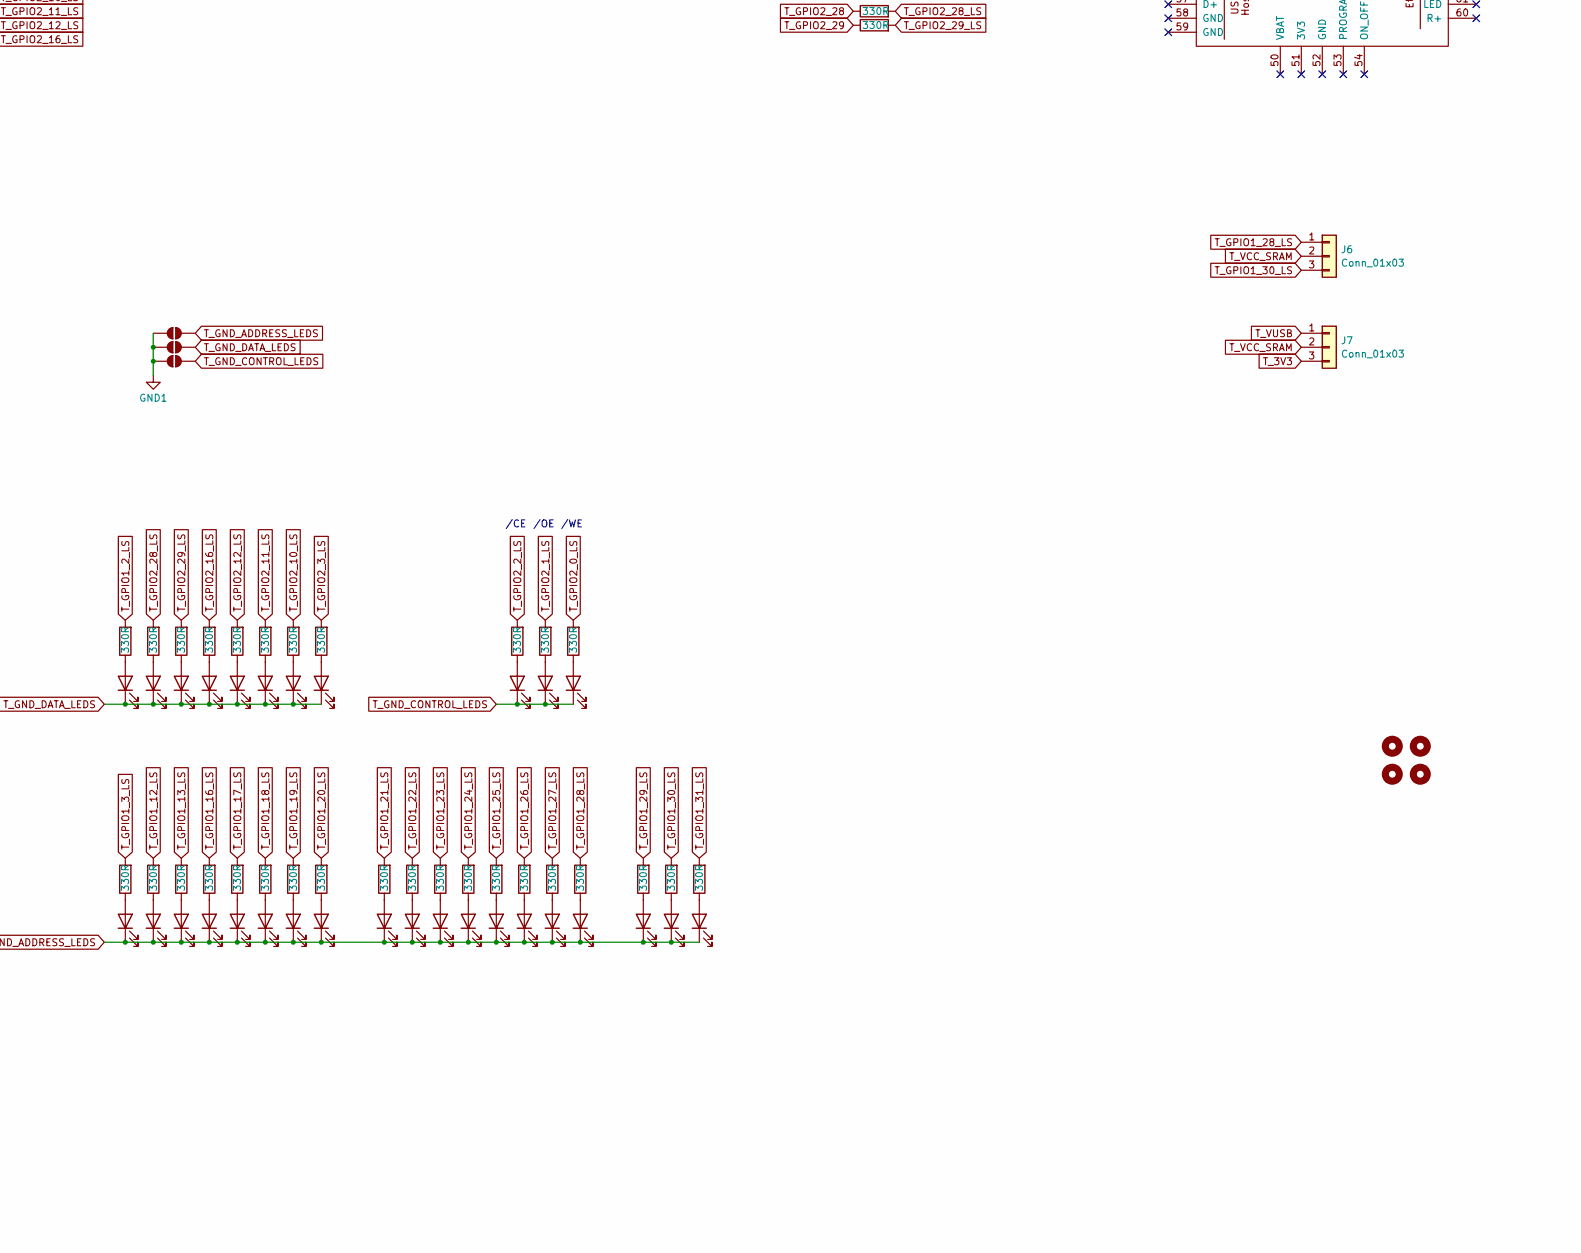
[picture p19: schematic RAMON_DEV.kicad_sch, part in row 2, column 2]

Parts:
D1, D2, D3, D4, D5, D6, D7, D8, D9, D10, D11, D12, D13, D14, D15, D16, D17, D18, D19, D20, D21, D22, D23, D24, D25, D26, D27, D28, D29, D30, D31, D32, D33, D34, D35: LED; LED_0805_2012Metric
H1, H2, H3, H4: MountingHole; MountingHole_3.2mm_M3
J1: Conn_02x16_Counter_Clockwise; DIP-32_W15.24mm_Socket
J2, J6, J7: Conn_01x03; PinHeader_1x03_P2.54mm_Vertical
J4: Conn_02x18_Counter_Clockwise; Hirose_FH12-36S-0.5SH_1x36-1MP_P0.50mm_Horizontal
J8: Conn_02x16_Counter_Clockwise; PinHeader_2x16_P2.54mm_Vertical_clockwise
JP1, JP2, JP3, JP4, JP5, JP6, JP7, JP8, JP9, JP10, JP11, JP12, JP13, JP14, JP15, JP16, JP17, JP18, JP19, JP20, JP21, JP22, JP23, JP24, JP25, JP26, JP27, JP28, JP29, JP30, JP31, JP32, JP33, JP34, JP35, JP38, JP41, JP42, JP43: SolderJumper_2_Open; SolderJumper-2_P1.3mm_Open_TrianglePad1.0x1.5mm
R1, R2, R3, R4, R5, R6, R7, R8, R9, R10, R11, R12, R13, R14, R15, R16, R17, R18, R19, R20, R21, R22, R23, R24, R25, R26, R27, R28, R31, R32, R33, R34, R35, R36, R37, R38, R39, R40, R41, R42, R43, R44, R45, R46, R47, R48, R49, R50, R51, R52, R53, R54, R55, R56, R57, R58, R59, R60, R63, R64, R65, R66, R67, R68, R69, R70, R71, R72, R73, R74, R75, R76, R77, R78, R79, R80, R81, R82, R83, R84, R85, R86, R87, R88, R89, R90, R91, R92, R93, R94, R95, R96, R97, R98, R99: 330R; R_0805_2012Metric
U1, U13: Teensy4.1; Teensy41

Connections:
3V3: R95.2, U1.46 (3V3)
GND: D31.1 (K), D32.1 (K), D33.1 (K), D34.1 (K), D35.1 (K), J4.17, J4.18, J4.19, J8.17, JP17.1 (A), U1.1 (GND), U1.34 (GND), U1.47 (GND)
GND1: J1.16, JP17.2 (B), JP41.1 (A), JP42.1 (A), JP43.1 (A), U13.1 (GND), U13.34 (GND), U13.47 (GND)
GPIO1_2: R1.1, U1.3 (1_TX1_CTX2_MISO1)
GPIO1_2_LS: J4.14, J8.20, JP14.1 (A), R1.2
GPIO1_3: R2.1, U1.2 (0_RX1_CRX2_CS1)
GPIO1_3_LS: J4.13, J8.21, JP13.1 (A), R2.2
GPIO1_12: R3.1, U1.16 (24_A10_TX6_SCL2)
GPIO1_12_LS: J4.12, J8.22, JP12.1 (A), R3.2
GPIO1_13: R4.1, U1.17 (25_A11_RX6_SDA2)
GPIO1_13_LS: J4.11, J8.23, JP11.1 (A), R4.2
GPIO1_16: R5.1, U1.41 (19_A5_SCL)
GPIO1_16_LS: J4.10, J8.24, JP10.1 (A), R5.2
GPIO1_17: R6.1, U1.40 (18_A4_SDA)
GPIO1_17_LS: J4.9, J8.25, JP9.1 (A), R6.2
GPIO1_18: R7.1, U1.36 (14_A0_TX3_SPDIF_OUT)
GPIO1_18_LS: J4.8, J8.26, JP8.1 (A), R7.2
GPIO1_19: R8.1, U1.37 (15_A1_RX3_SPDIF_IN)
GPIO1_19_LS: J4.7, J8.27, JP7.1 (A), R8.2
GPIO1_20: R9.1, U1.32 (40_A16)
GPIO1_20_LS: J4.6, J8.28, JP6.1 (A), R9.2
GPIO1_21: R10.1, U1.33 (41_A17)
GPIO1_21_LS: J4.30, J8.6, JP24.1 (A), R10.2
GPIO1_22: R11.1, U1.39 (17_A3_TX4_SDA1)
GPIO1_22_LS: J4.29, J8.7, JP25.1 (A), R11.2
GPIO1_23: R12.1, U1.38 (16_A2_RX4_SCL1)
GPIO1_23_LS: J4.26, J8.10, JP28.1 (A), R12.2
GPIO1_24: R13.1, U1.44 (22_A8_CTX1)
GPIO1_24_LS: J4.28, J8.8, JP26.1 (A), R13.2
GPIO1_25: R14.1, U1.45 (23_A9_CRX1_MCLK1)
GPIO1_25_LS: J4.5, J8.29, JP5.1 (A), R14.2
GPIO1_26: R15.1, U1.42 (20_A6_TX5_LRCLK1)
GPIO1_26_LS: J4.31, J8.5, JP23.1 (A), R15.2
GPIO1_27: R16.1, U1.43 (21_A7_RX5_BCLK1)
GPIO1_27_LS: J4.4, J8.30, JP4.1 (A), R16.2
GPIO1_28: R17.1, U1.30 (38_CS1_IN1)
GPIO1_28_LS: J2.1, J4.34, J8.2, JP20.1 (A), R17.2
GPIO1_29: R18.1, U1.31 (39_MISO1_OUT1A)
GPIO1_29_LS: J4.3, J8.31, JP3.1 (A), R18.2
GPIO1_30: R19.1, U1.18 (26_A12_MOSI1)
GPIO1_30_LS: J2.3, J4.33, J8.3, JP21.1 (A), R19.2
GPIO1_31: R20.1, U1.19 (27_A13_SCK1)
GPIO1_31_LS: J4.2, J8.32, JP2.1 (A), R20.2
GPIO2_0: R21.1, U1.12 (10_CS_MQSR)
GPIO2_0_LS: J4.32, J8.4, JP22.1 (A), R21.2, R99.2
GPIO2_1: R22.1, U1.14 (12_MISO_MQSL)
GPIO2_1_LS: J4.27, J8.9, JP27.1 (A), R22.2, R98.2
GPIO2_2: R23.1, U1.13 (11_MOSI_CTX1)
GPIO2_2_LS: J4.25, J8.11, JP29.1 (A), R23.2, R97.2
GPIO2_3: R24.1, U1.35 (13_SCK_LED)
GPIO2_3_LS: J4.24, J8.12, JP30.1 (A), R24.2
GPIO2_10: R25.1, U1.8 (6_OUT1D)
GPIO2_10_LS: J4.23, J8.13, JP31.1 (A), R25.2
GPIO2_11: R26.1, U1.11 (9_OUT1C)
GPIO2_11_LS: J4.22, J8.14, JP32.1 (A), R26.2
GPIO2_12: R27.1, U1.24 (32_OUT1B)
GPIO2_12_LS: J4.21, J8.15, JP33.1 (A), R27.2
GPIO2_16: R28.1, U1.10 (8_TX2_IN1)
GPIO2_16_LS: J4.20, J8.16, JP34.1 (A), R28.2
GPIO2_28: R31.1, U1.27 (35_TX8)
GPIO2_28_LS: J4.15, J8.19, JP15.1 (A), R31.2
GPIO2_29: R32.1, U1.26 (34_RX8)
GPIO2_29_LS: J4.16, J8.18, JP16.1 (A), R32.2
unnamed: D1.2 (A), R65.1
unnamed: D2.2 (A), R66.1
unnamed: D3.2 (A), R67.1
unnamed: D4.2 (A), R68.1
unnamed: D5.2 (A), R69.1
unnamed: D6.2 (A), R70.1
unnamed: D7.2 (A), R71.1
unnamed: D8.2 (A), R72.1
unnamed: D9.2 (A), R73.1
unnamed: D10.2 (A), R74.1
unnamed: D11.2 (A), R75.1
unnamed: D12.2 (A), R76.1
unnamed: D13.2 (A), R77.1
unnamed: D14.2 (A), R78.1
unnamed: D15.2 (A), R79.1
unnamed: D16.2 (A), R80.1
unnamed: D17.2 (A), R81.1
unnamed: D18.2 (A), R82.1
unnamed: D19.2 (A), R83.1
unnamed: D20.2 (A), R84.1
unnamed: D21.2 (A), R85.1
unnamed: D22.2 (A), R86.1
unnamed: D23.2 (A), R87.1
unnamed: D24.2 (A), R88.1
unnamed: D25.2 (A), R89.1
unnamed: D26.2 (A), R90.1
unnamed: D27.2 (A), R91.1
unnamed: D28.2 (A), R92.1
unnamed: D29.2 (A), R93.1
unnamed: D30.2 (A), R94.1
unnamed: D31.2 (A), R95.1
unnamed: D32.2 (A), R96.1
unnamed: D33.2 (A), R97.1
unnamed: D34.2 (A), R98.1
unnamed: D35.2 (A), R99.1
unnamed: J1.1, JP18.2 (B)
unnamed: J1.2, JP1.2 (B)
unnamed: J1.31, JP38.1 (A)
unnamed: J1.32, JP35.1 (A)
OE: U1.25 (33_MCLK2)
T_3V3: J7.3, U13.46 (3V3)
T_GND_ADDRESS_LEDS: D1.1 (K), D10.1 (K), D11.1 (K), D12.1 (K), D13.1 (K), D14.1 (K), D15.1 (K), D16.1 (K), D17.1 (K), D18.1 (K), D19.1 (K), D20.1 (K), D21.1 (K), D22.1 (K), D23.1 (K), D24.1 (K), D25.1 (K), D26.1 (K), D27.1 (K), JP41.2 (B)
T_GND_CONTROL_LEDS: D28.1 (K), D29.1 (K), D30.1 (K), JP43.2 (B)
T_GND_DATA_LEDS: D2.1 (K), D3.1 (K), D4.1 (K), D5.1 (K), D6.1 (K), D7.1 (K), D8.1 (K), D9.1 (K), JP42.2 (B)
T_GPIO1_2: R33.1, U13.3 (1_TX1_CTX2_MISO1)
T_GPIO1_2_LS: J1.13, JP14.2 (B), R33.2, R66.2
T_GPIO1_3: R34.1, U13.2 (0_RX1_CRX2_CS1)
T_GPIO1_3_LS: J1.12, JP13.2 (B), R34.2, R65.2
T_GPIO1_12: R35.1, U13.16 (24_A10_TX6_SCL2)
T_GPIO1_12_LS: J1.11, JP12.2 (B), R35.2, R74.2
T_GPIO1_13: R36.1, U13.17 (25_A11_RX6_SDA2)
T_GPIO1_13_LS: J1.10, JP11.2 (B), R36.2, R75.2
T_GPIO1_16: R37.1, U13.41 (19_A5_SCL)
T_GPIO1_16_LS: J1.9, JP10.2 (B), R37.2, R76.2
T_GPIO1_17: R38.1, U13.40 (18_A4_SDA)
T_GPIO1_17_LS: J1.8, JP9.2 (B), R38.2, R77.2
T_GPIO1_18: R39.1, U13.36 (14_A0_TX3_SPDIF_OUT)
T_GPIO1_18_LS: J1.7, JP8.2 (B), R39.2, R78.2
T_GPIO1_19: R40.1, U13.37 (15_A1_RX3_SPDIF_IN)
T_GPIO1_19_LS: J1.6, JP7.2 (B), R40.2, R79.2
T_GPIO1_20: R41.1, U13.32 (40_A16)
T_GPIO1_20_LS: J1.5, JP6.2 (B), R41.2, R80.2
T_GPIO1_21: R42.1, U13.33 (41_A17)
T_GPIO1_21_LS: J1.27, JP24.2 (B), R42.2, R81.2
T_GPIO1_22: R43.1, U13.39 (17_A3_TX4_SDA1)
T_GPIO1_22_LS: J1.26, JP25.2 (B), R43.2, R82.2
T_GPIO1_23: R44.1, U13.38 (16_A2_RX4_SCL1)
T_GPIO1_23_LS: J1.23, JP28.2 (B), R44.2, R83.2
T_GPIO1_24: R45.1, U13.44 (22_A8_CTX1)
T_GPIO1_24_LS: J1.25, JP26.2 (B), R45.2, R84.2
T_GPIO1_25: R46.1, U13.45 (23_A9_CRX1_MCLK1)
T_GPIO1_25_LS: J1.4, JP5.2 (B), R46.2, R85.2
T_GPIO1_26: R47.1, U13.42 (20_A6_TX5_LRCLK1)
T_GPIO1_26_LS: J1.28, JP23.2 (B), R47.2, R86.2
T_GPIO1_27: R48.1, U13.43 (21_A7_RX5_BCLK1)
T_GPIO1_27_LS: J1.3, JP4.2 (B), R48.2, R87.2
T_GPIO1_28: R49.1, U13.30 (38_CS1_IN1)
T_GPIO1_28_LS: J6.1, JP20.2 (B), JP38.2 (B), R49.2, R88.2
T_GPIO1_29: R50.1, U13.31 (39_MISO1_OUT1A)
T_GPIO1_29_LS: JP1.1 (A), JP3.2 (B), R50.2, R89.2
T_GPIO1_30: R51.1, U13.18 (26_A12_MOSI1)
T_GPIO1_30_LS: J1.30, J6.3, JP21.2 (B), R51.2, R90.2
T_GPIO1_31: R52.1, U13.19 (27_A13_SCK1)
T_GPIO1_31_LS: JP2.2 (B), JP18.1 (A), R52.2, R91.2
T_GPIO2_0: R53.1, U13.12 (10_CS_MQSR)
T_GPIO2_0_LS: J1.29, JP22.2 (B), R53.2, R94.2
T_GPIO2_1: R54.1, U13.14 (12_MISO_MQSL)
T_GPIO2_1_LS: J1.24, JP27.2 (B), R54.2, R93.2
T_GPIO2_2: R55.1, U13.13 (11_MOSI_CTX1)
T_GPIO2_2_LS: J1.22, JP29.2 (B), R55.2, R92.2
T_GPIO2_3: R56.1, U13.35 (13_SCK_LED)
T_GPIO2_3_LS: J1.21, JP30.2 (B), R56.2, R73.2
T_GPIO2_10: R57.1, U13.8 (6_OUT1D)
T_GPIO2_10_LS: J1.20, JP31.2 (B), R57.2, R72.2
T_GPIO2_11: R58.1, U13.11 (9_OUT1C)
T_GPIO2_11_LS: J1.19, JP32.2 (B), R58.2, R71.2
T_GPIO2_12: R59.1, U13.24 (32_OUT1B)
T_GPIO2_12_LS: J1.18, JP33.2 (B), R59.2, R70.2
T_GPIO2_16: R60.1, U13.10 (8_TX2_IN1)
T_GPIO2_16_LS: J1.17, JP34.2 (B), R60.2, R69.2
T_GPIO2_28: R63.1, U13.27 (35_TX8)
T_GPIO2_28_LS: J1.14, JP15.2 (B), R63.2, R67.2
T_GPIO2_29: R64.1, U13.26 (34_RX8)
T_GPIO2_29_LS: J1.15, JP16.2 (B), R64.2, R68.2
T_OE: U13.25 (33_MCLK2)
T_VCC_SRAM: J6.2, J7.2, JP19.2 (B), JP35.2 (B)
T_VUSB: J7.1, U13.49 (VUSB)
VCC_SRAM: J2.2, J4.1, J4.35, J4.36, J8.1, JP19.1 (A), R96.2

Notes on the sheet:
CAN BE VCC_SRAM
Wij hebben: 923690-28
/OE
/WE
/CE
SRAM MONITOR
FFC / FPC connector
MIRROR CLIPPERS
Clippers: https://multimedia.3m.com/mws/media/490562O/test-clip-brochure.pdf?&fn=Test-Clip-Broch-98_R1.pdf
TEST SETUP FOR RAM MONITOR
Male pinheader for clipper (must be mirrored)

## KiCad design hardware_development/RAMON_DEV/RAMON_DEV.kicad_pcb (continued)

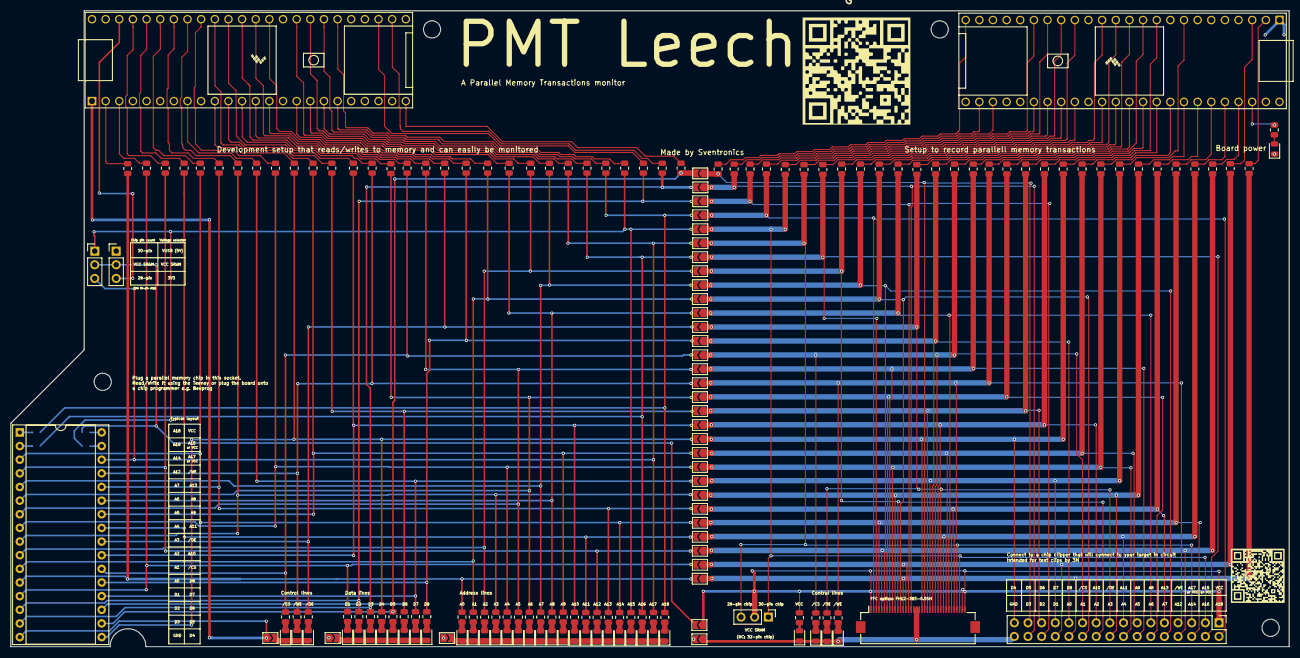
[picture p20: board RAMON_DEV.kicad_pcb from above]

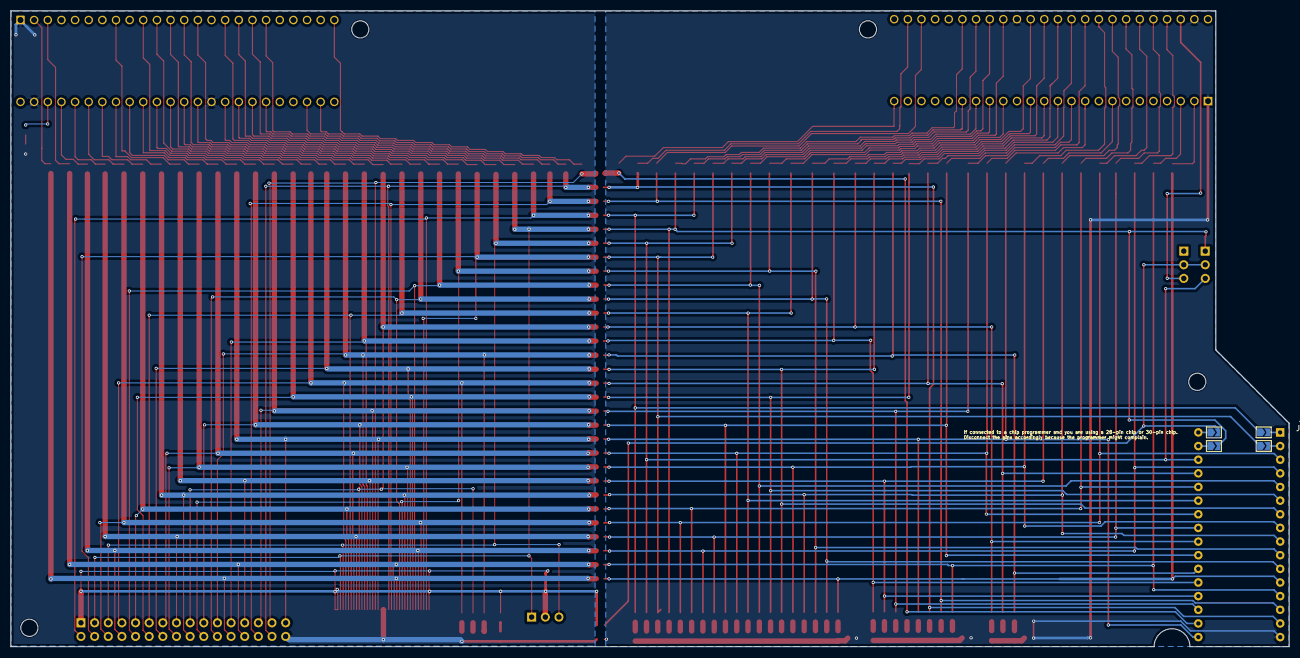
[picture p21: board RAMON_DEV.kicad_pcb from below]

Board: 2 copper layers, 238.0 x 118.3 mm, 181 parts (4 on the bottom side), 168 nets.

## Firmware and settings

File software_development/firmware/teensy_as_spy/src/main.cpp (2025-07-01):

#include <Arduino.h>
#include <EEPROM.h>
#include <SD.h>


#define EEPROM_MAGIC 0x42
#define EEPROM_MAGIC_ADDR 0
#define EEPROM_CONFIG_ADDR 1  // start config at address 1

//Special pins:
#define RUNNING_PIN 2
#define EXT_CLK_PIN 3
#define EXTRA_PIN_1 4
#define MEMORY_VCC_CONTROL 5
#define EXTRA_PIN_2 7
#define SERIAL7_RX 28
#define SERIAL7_TX 29
#define DEBUG_SPEED_CLK_ACTIVE_LED 30
#define RESET_CPU_PIN 31 
#define EXTRA_PIN_4 37
#define EXTRA_PIN_3 36
#define HIGH_SPEED_CLK_ACTIVE_LED 33

#define MEMORY_CHIP_WRITE_DELAY_MS 10 // Needs a lot time ms vs us because we drive signals through 330R resistors!! (min. value = 5ms), maybe better without leds on WE signal?
#define MEMORY_CHIP_READ_DELAY_US 10

uint16_t MEMORY_CHIP_WRITE_DELAY_US = 10000;

enum State : uint8_t {
  IDLE = 0,
  RUNNING = 1,
  EMULATING = 2
};

struct Config {
  uint8_t we_pin;
  uint8_t oe_pin;
  uint8_t cs_pin; 
  uint32_t freq;
  uint32_t xtal_freq;
  uint8_t idle_behavior; // 0 = halt, 1 = run at XTAL
  char chip_name[30];
  uint8_t address_pins[24]; // A1–A24 max
  uint8_t address_count;
  uint8_t data_pins[16];    // D1–D16 max
  uint8_t data_count;
};


Config config;
State state = IDLE;

volatile uint32_t gpio_data[2];
volatile bool dataset_ready = false;

IntervalTimer sample_timer;

EXTMEM uint8_t psram_buffer[1 << 18];  // 2^18 = 262144 bytes = 256 KB
uint8_t temp_buf[1024];  // temporary buffer for memory writes

// Global reusable packet buffer with static prefix pre-filled
uint8_t gpio_packet_buffer[10] = { '>', 0xFF };  // Remaining 8 bytes will be filled with gpio64
volatile bool instruction_transmitted = false;

uint64_t pin_mask_table[128];

void build_pin_mask_table() {
  for (int pin = 0; pin < 128; ++pin) {
    const struct digital_pin_bitband_and_config_table_struct *p = &digital_pin_to_info_PGM[pin];
    if (!p) continue;

    // Only handle pins in GPIO6 or GPIO7
    if (p->reg == &GPIO6_DR) {
      pin_mask_table[pin] = (1ULL << (p->mask ? __builtin_ctz(p->mask) : 0));
    } else if (p->reg == &GPIO7_DR) {
      pin_mask_table[pin] = (1ULL << (32 + (p->mask ? __builtin_ctz(p->mask) : 0)));
    } else {
      pin_mask_table[pin] = 0; // Unsupported GPIO group
    }
  }
}

FASTRUN void handle_memory_access() {
  if (Serial.availableForWrite() >= 10) {  // needs 10, not 8
    uint64_t gpio64 = ((uint64_t)GPIO7_DR << 32) | GPIO6_DR;
    memcpy(&gpio_packet_buffer[2], &gpio64, 8);
    Serial.write(gpio_packet_buffer, 10);
    instruction_transmitted = true;
  }
}

FASTRUN void handle_memory_access_extracted() {
  if (Serial.availableForWrite() < 9) return;

  uint64_t gpio64 = ((uint64_t)GPIO7_DR << 32) | GPIO6_DR;

  // Decode control lines
  bool cs_low = !(gpio64 & pin_mask_table[config.cs_pin]);
  bool we_low = !(gpio64 & pin_mask_table[config.we_pin]);
  bool oe_low = !(gpio64 & pin_mask_table[config.oe_pin]);

  // Decode address (18-bit max)
  uint32_t address = 0;
  for (uint8_t i = 0; i < config.address_count; ++i) {
    if (gpio64 & pin_mask_table[config.address_pins[i]])
      address |= (1UL << i);
  }

  // Decode data
  uint8_t data = 0;
  for (uint8_t i = 0; i < config.data_count; ++i) {
    if (gpio64 & pin_mask_table[config.data_pins[i]])
      data |= (1 << i);
  }

  gpio_packet_buffer[0] = '>';
  gpio_packet_buffer[1] = 'P';
  gpio_packet_buffer[2] = cs_low;
  gpio_packet_buffer[3] = we_low;
  gpio_packet_buffer[4] = oe_low;
  gpio_packet_buffer[5] = (address >> 16) & 0xFF;
  gpio_packet_buffer[6] = (address >> 8) & 0xFF;
  gpio_packet_buffer[7] = address & 0xFF;
  gpio_packet_buffer[8] = data;

  Serial.write(gpio_packet_buffer, 9);
  instruction_transmitted = true;
}


// FASTRUN void spy_to_psram() {
//   uint64_t gpio64 = ((uint64_t)GPIO7_DR << 32) | GPIO6_DR;

//   // Check access condition first
//   bool cs_low = !(gpio64 & pin_mask_table[config.cs_pin]);
//   bool we_low = !(gpio64 & pin_mask_table[config.we_pin]);
//   bool oe_low = !(gpio64 & pin_mask_table[config.oe_pin]);

//   if (!(cs_low && (we_low || oe_low))) return;

//   uint32_t address = 0;
//   for (uint8_t i = 0; i < config.address_count; ++i) {
//     if (gpio64 & pin_mask_table[config.address_pins[i]])
//       address |= (1UL << i);
//   }

//   uint8_t data = 0;
//   for (uint8_t i = 0; i < config.data_count; ++i) {
//     if (gpio64 & pin_mask_table[config.data_pins[i]])
//       data |= (1 << i);
//   }

//   if (psram_buffer[address] != data)
//     psram_buffer[address] = data;
// }

bool isvalidpin(uint8_t pin){
  return pin <= 40;
}


void save_config_to_eeprom() {
  EEPROM.write(EEPROM_MAGIC_ADDR, EEPROM_MAGIC);
  EEPROM.put(EEPROM_CONFIG_ADDR, config);
}

void send_pc(char type, const String& message) {
  // Calculate total payload size: type + message
  uint16_t payload_len = 1 + message.length();  // 1 byte for type char

  // Send header
  Serial.write('>');  // Start of message
  Serial.write((payload_len >> 8) & 0xFF);  // High byte
  Serial.write(payload_len & 0xFF);         // Low byte

  // Send type + message
  Serial.write(type);           // Type as single byte
  Serial.print(message);        // Message content as ASCII
}

void send_pc(char type, const uint8_t* data, uint16_t len) {
  uint16_t payload_len = 1 + len;

  // Send header
  Serial.write('>');
  Serial.write((payload_len >> 8) & 0xFF);
  Serial.write(payload_len & 0xFF);

  // Send type and raw data
  Serial.write(type);
  Serial.write(data, len);
}

void load_config_from_eeprom() {
  if (EEPROM.read(EEPROM_MAGIC_ADDR) == EEPROM_MAGIC) {
    EEPROM.get(EEPROM_CONFIG_ADDR, config);
  } else {

    send_pc('I', "Using default values!");

    config.we_pin = 10;
    config.oe_pin = 12;
    config.cs_pin = 11;
    config.freq = 70000;
    config.xtal_freq = 16000000;
    config.idle_behavior = 0;
    strncpy(config.chip_name, "AT28C64B", sizeof(config.chip_name) - 1);
    config.chip_name[sizeof(config.chip_name) - 1] = '\0';

    uint8_t default_addr[] = {0, 24, 25, 19, 18, 14, 15, 40, 41, 17, 16, 22, 23};
    config.address_count = sizeof(default_addr);
    memcpy(config.address_pins, default_addr, config.address_count);

    uint8_t default_data[] = {1, 35, 34, 8, 32, 9, 6, 13};
    config.data_count = sizeof(default_data);
    memcpy(config.data_pins, default_data, config.data_count);
  }
}

bool setup_for_reading_writing_chip(){


  if(config.we_pin == (uint8_t)-1){
    send_pc('E', "Error WE PIN");
    return false;
  }

  if(config.cs_pin == (uint8_t)-1){
    send_pc('E', "Error CS PIN");
    return false;
  }

  if(config.oe_pin == (uint8_t)-1){
    send_pc('E', "Error OE PIN");
    return false;
  }

  pinMode(RESET_CPU_PIN, OUTPUT);
  digitalWriteFast(RESET_CPU_PIN, LOW);

  pinMode(config.cs_pin, OUTPUT);
  pinMode(config.oe_pin, OUTPUT);
  pinMode(config.we_pin, OUTPUT);

  // Serial.println(config.cs_pin);
  // Serial.println(config.we_pin);
  // Serial.println(config.oe_pin);

  // Make sure we cannot write accidently...
  digitalWriteFast(config.cs_pin, HIGH);
  digitalWriteFast(config.we_pin, HIGH);
  digitalWriteFast(config.oe_pin, HIGH);  

  digitalWrite(MEMORY_VCC_CONTROL, LOW); // VCC = ON -> power the chip
  
  digitalWriteFast(config.cs_pin, LOW);

  for (uint8_t i = 0; i < config.address_count; ++i)
    pinMode(config.address_pins[i], OUTPUT);

  return true;
}

void set_memory_address(uint32_t addr){
  for (uint8_t j = 0; j < config.address_count; ++j)
    digitalWriteFast(config.address_pins[j], (addr >> j) & 1); // set address lines
}

void set_memory_value(uint8_t value){
  for (uint8_t j = 0; j < config.data_count; ++j)
    digitalWriteFast(config.data_pins[j], (value >> j) & 1); // set data lines
}

uint8_t read_memory_value(){
  uint8_t data = 0;
  for (uint8_t i = 0; i < config.data_count; ++i)
    if (digitalReadFast(config.data_pins[i])) data |= (1 << i);

  return data;
}

void close_memory_power_and_set_pins_high_impedance(){
  digitalWriteFast(config.we_pin, HIGH); // disable chip writing
  digitalWriteFast(config.oe_pin, HIGH); // disable data output
  digitalWriteFast(config.cs_pin, HIGH); // disable chip entirely

  //set all pins high impedance
  for (uint8_t i = 0; i < config.address_count; ++i)
    pinMode(config.address_pins[i], INPUT);
  for (uint8_t i = 0; i < config.data_count; ++i)
    pinMode(config.data_pins[i], INPUT);

  delay(50); // CRUCIAL OTHERWISE WRITES FAIL

  digitalWriteFast(MEMORY_VCC_CONTROL, HIGH); // stop powering the chip

  pinMode(config.oe_pin, INPUT);
  pinMode(config.we_pin, INPUT);
  pinMode(config.cs_pin, INPUT);

  pinMode(RESET_CPU_PIN, INPUT);
}

uint8_t read_single_address(uint32_t addr){
  // Serial.print("Reading address ");
  // Serial.print(String(addr));

  if(!setup_for_reading_writing_chip())return;

  set_memory_address(addr);

  digitalWriteFast(config.oe_pin, LOW); // enable reading to chip
  delayMicroseconds(MEMORY_CHIP_READ_DELAY_US);
  // delay(1000);
  uint8_t value = read_memory_value();

  close_memory_power_and_set_pins_high_impedance();

  // Serial.print(" value: ");
  // Serial.println(value);

  return value;
}

void send_partial_memory_from_psram(uint32_t start_addr, uint32_t length){
  const size_t MAX_DATA_PER_PACKET = 500;

  uint32_t addr = start_addr;
  while (addr < start_addr + length) {
    size_t chunk_len = min(MAX_DATA_PER_PACKET, (start_addr + length) - addr);

    // Compose message into a temporary buffer
    uint8_t buf[5 + MAX_DATA_PER_PACKET]; // 4 for addr, 1 for '.', then data
    buf[0] = (addr >> 24) & 0xFF;
    buf[1] = (addr >> 16) & 0xFF;
    buf[2] = (addr >> 8) & 0xFF;
    buf[3] = (addr >> 0) & 0xFF;

    for (size_t i = 0; i < chunk_len; ++i) {
      uint32_t curr_addr = addr + i;
      buf[4 + i] = psram_buffer[curr_addr];
    }

    delay(10);
    send_pc('R', buf, 4 + chunk_len);
    addr += chunk_len;
  }

  char buf[64];
  snprintf(buf, sizeof(buf), "done reading %lu bytes from address 0x%lX", length, start_addr);
  send_pc('I', String(buf));

}

void read_partial_memory(uint32_t start_addr, uint32_t length) {
  
  uint32_t max_address = (1UL << config.address_count);

  // Default to full memory size if length == 0
  if (length == 0) {
    length = max_address - start_addr;
  }

  if (start_addr + length > max_address) {
    send_pc('I', "ERROR: Out of bounds");
    return;
  }

  if(!setup_for_reading_writing_chip())return;

  digitalWriteFast(config.oe_pin, LOW); // enable reading from chip

  uint32_t addr = start_addr;
  while (addr < start_addr + length) {
    set_memory_address(addr);
    delayMicroseconds(MEMORY_CHIP_READ_DELAY_US);
    psram_buffer[addr] = read_memory_value();
    addr++;
  }

  close_memory_power_and_set_pins_high_impedance();

  send_partial_memory_from_psram(start_addr, length);
}

void write_single_address_test(uint32_t addr, const uint8_t value){
  // Serial.print("Writing address ");
  // Serial.print(String(addr));
  // Serial.print(" value: ");
  // Serial.println(String(value));

  if(!setup_for_reading_writing_chip())return;

  for (uint8_t i = 0; i < config.data_count; ++i)
    pinMode(config.data_pins[i], OUTPUT);

  set_memory_address(addr);
  set_memory_value(value);

  digitalWriteFast(config.we_pin, LOW); // enable writing to chip
  delayMicroseconds(MEMORY_CHIP_WRITE_DELAY_US);  // give a good 10ms to chip so write has certainly happenned // Needs a lot time ms vs us because we drive signals through 330R resistors!!
  close_memory_power_and_set_pins_high_impedance();
}

void write_single_address(uint32_t addr, const uint8_t value){
  // Serial.print("Writing address ");
  // Serial.print(String(addr));
  // Serial.print(" value: ");
  // Serial.println(String(value));

  if(!setup_for_reading_writing_chip())return;

  for (uint8_t i = 0; i < config.data_count; ++i)
    pinMode(config.data_pins[i], OUTPUT);

  set_memory_address(addr);
  set_memory_value(value);

  digitalWriteFast(config.we_pin, LOW); // enable writing to chip
  delay(MEMORY_CHIP_WRITE_DELAY_MS);  // give a good 10ms to chip so write has certainly happenned // Needs a lot time ms vs us because we drive signals through 330R resistors!!
  close_memory_power_and_set_pins_high_impedance();
}

void write_partial_memory_old(uint32_t start_addr, const uint8_t* data, uint32_t length) {
  uint32_t max_address = (1UL << config.address_count);

  if (start_addr + length > max_address) {
    send_pc('I', "ERROR: Write out of bounds");
    return;
  }

  if(!setup_for_reading_writing_chip())return;

  for (uint8_t i = 0; i < config.data_count; ++i)
    pinMode(config.data_pins[i], OUTPUT);

  for (uint32_t i = 0; i < length; ++i) {
    uint32_t curr_addr = start_addr + i;
    uint8_t value = data[i];

    set_memory_address(curr_addr);
    //set_memory_value(value);

    digitalWriteFast(config.we_pin, LOW); // enable writing to chip
    set_memory_value(value);
    delay(MEMORY_CHIP_WRITE_DELAY_MS);  // give a good 10ms to chip so write has certainly happenned // Needs a lot time ms vs us because we drive signals through 330R resistors!!
    digitalWriteFast(config.we_pin, HIGH);
    //delay(MEMORY_CHIP_WRITE_DELAY_MS);
  }

  close_memory_power_and_set_pins_high_impedance();

  char msg[64];
  snprintf(msg, sizeof(msg), "WROTE %lu bytes to address 0x%lX", length, start_addr);
  send_pc('I', String(msg));
}

void psram_to_chip_write() {
  uint32_t max_address = (1UL << config.address_count);

  if (!setup_for_reading_writing_chip()) return;

  for (uint8_t i = 0; i < config.data_count; ++i)
    pinMode(config.data_pins[i], OUTPUT);

  // Send initial progress update
  send_pc('I', "<0> % writing done");

  const uint32_t chunk_size = 512;
  for (uint32_t curr_addr = 0; curr_addr < max_address; ++curr_addr) {
    set_memory_address(curr_addr);
    digitalWriteFast(config.we_pin, LOW);  // enable writing to chip
    set_memory_value(psram_buffer[curr_addr]);
    delay(MEMORY_CHIP_WRITE_DELAY_MS);     // hold WE low for write time
    digitalWriteFast(config.we_pin, HIGH);
    delay(MEMORY_CHIP_WRITE_DELAY_MS);

    // Progress feedback every 512 bytes
    if ((curr_addr + 1) % chunk_size == 0 || (curr_addr + 1) == max_address) {
      uint32_t percent = ((curr_addr + 1) * 100UL) / max_address;
      char buf[32];
      snprintf(buf, sizeof(buf), "<%lu> %% writing done", percent);
      send_pc('I', buf);
    }
  }

  close_memory_power_and_set_pins_high_impedance();

  send_pc('I', "writing done!");
}


void write_partial_memory(uint32_t start_addr, const uint8_t* data, uint32_t length) {
  uint32_t max_address = (1UL << config.address_count);

  if (start_addr + length > max_address) {
    send_pc('I', "ERROR: Write out of bounds");
    return;
  }

  for (uint8_t i = 0; i < config.data_count; ++i)
    pinMode(config.data_pins[i], OUTPUT);

  for (uint32_t i = 0; i < length; ++i) {
    psram_buffer[start_addr + i] = data[i];
  }

  char msg[64];
  snprintf(msg, sizeof(msg), "WROTE %lu bytes to address 0x%lX", length, start_addr);
  send_pc('I', String(msg));
}

void dump_memory_to_sd() {
  if (!SD.begin(BUILTIN_SDCARD)) {
    send_pc('I', "ERROR: No SD card or init failed.");
    return;
  }

  char filename[40];
  snprintf(filename, sizeof(filename), "/%s.bin", config.chip_name);

  File file = SD.open(filename, FILE_WRITE);
  if (!file) {
    send_pc('I', "ERROR: Could not create file.");
    return;
  }

  uint32_t max_address = (1UL << config.address_count);

  // Set WE pin HIGH before enabling memory power
  if (config.we_pin != (uint8_t)-1) {
    pinMode(config.we_pin, OUTPUT);
    digitalWriteFast(config.we_pin, HIGH);
  }

  pinMode(config.cs_pin, OUTPUT);
  digitalWriteFast(config.cs_pin, HIGH);

  digitalWrite(MEMORY_VCC_CONTROL, LOW);

  for (uint8_t i = 0; i < config.address_count; ++i)
    pinMode(config.address_pins[i], OUTPUT);
  for (uint8_t i = 0; i < config.data_count; ++i)
    pinMode(config.data_pins[i], INPUT);

  pinMode(config.oe_pin, OUTPUT);
  digitalWriteFast(config.cs_pin, LOW);
  digitalWriteFast(config.oe_pin, LOW);

  const size_t BUF_SIZE = 512;
  uint8_t buffer[BUF_SIZE];
  size_t buf_index = 0;

  for (uint32_t addr = 0; addr < max_address; ++addr) {
    for (uint8_t i = 0; i < config.address_count; ++i)
      digitalWriteFast(config.address_pins[i], (addr >> i) & 1);

    delayMicroseconds(1);  // settling time

    uint8_t data = 0;
    for (uint8_t i = 0; i < config.data_count; ++i)
      if (digitalReadFast(config.data_pins[i])) data |= (1 << i);

    buffer[buf_index++] = data;
    if (buf_index == BUF_SIZE) {
      file.write(buffer, BUF_SIZE);
      buf_index = 0;
    }
  }

  if (buf_index > 0) {
    file.write(buffer, buf_index);
  }

  file.close();

  digitalWriteFast(config.cs_pin, HIGH);
  digitalWriteFast(config.oe_pin, HIGH);
  if (config.we_pin != (uint8_t)-1)
    digitalWriteFast(config.we_pin, HIGH);

  digitalWrite(MEMORY_VCC_CONTROL, HIGH);

  for (uint8_t i = 0; i < config.address_count; ++i)
    pinMode(config.address_pins[i], INPUT);
  for (uint8_t i = 0; i < config.data_count; ++i)
    pinMode(config.data_pins[i], INPUT);

  pinMode(config.cs_pin, INPUT);
  pinMode(config.oe_pin, INPUT);
  if (config.we_pin != (uint8_t)-1)
    pinMode(config.we_pin, INPUT);

  char buf[100];
  snprintf(buf, sizeof(buf), "Dumped %lu bytes to %s", max_address, filename);
  send_pc('I', String(buf));
}

void enter_running_mode() {
  if (config.we_pin != (uint8_t)-1) {
    pinMode(config.we_pin, INPUT);
    attachInterrupt(digitalPinToInterrupt(config.we_pin), handle_memory_access, FALLING);
  }
  if (config.oe_pin != (uint8_t)-1) {
    pinMode(config.oe_pin, INPUT);
    attachInterrupt(digitalPinToInterrupt(config.oe_pin), handle_memory_access, FALLING);
  }

  digitalWrite(DEBUG_SPEED_CLK_ACTIVE_LED, HIGH);
  digitalWrite(HIGH_SPEED_CLK_ACTIVE_LED, LOW);
  analogWriteFrequency(EXT_CLK_PIN, config.freq);
  analogWrite(EXT_CLK_PIN, 128);  // 50% duty cycle

  digitalWrite(RUNNING_PIN, HIGH);
  state = RUNNING;
}

void enter_idle_mode() {

  if (config.we_pin != (uint8_t)-1) {
    detachInterrupt(digitalPinToInterrupt(config.we_pin));
  }
  if (config.oe_pin != (uint8_t)-1) {
    detachInterrupt(digitalPinToInterrupt(config.oe_pin));
  }

  if (config.idle_behavior == 1 && config.xtal_freq > 0) {
    // ✳️ XTAL mode — run EXT_CLK at specified xtal_freq
    digitalWrite(DEBUG_SPEED_CLK_ACTIVE_LED, LOW);
    digitalWrite(HIGH_SPEED_CLK_ACTIVE_LED, HIGH);
    analogWriteFrequency(EXT_CLK_PIN, config.xtal_freq);
    analogWrite(EXT_CLK_PIN, 128); // 50% duty
  } else {
    // ❌ HALT mode — disable clock
    digitalWrite(DEBUG_SPEED_CLK_ACTIVE_LED, LOW);
    digitalWrite(HIGH_SPEED_CLK_ACTIVE_LED, LOW);
    analogWrite(EXT_CLK_PIN, 0);          // Optional: reduces duty to 0%
    digitalWriteFast(EXT_CLK_PIN, LOW);   // Drive LOW
  }

  digitalWrite(RUNNING_PIN, LOW);
  state = IDLE;

  send_pc('I', "ACK IDLE");
}

void enter_emulate_mode() {
  state = EMULATING;

  // Set up address pins as INPUT
  for (uint8_t i = 0; i < config.address_count; ++i) {
    pinMode(config.address_pins[i], INPUT);
  }

  // Set up data pins as OUTPUT
  for (uint8_t i = 0; i < config.data_count; ++i) {
    pinMode(config.data_pins[i], OUTPUT);
  }

  // Disable memory chip power output
  digitalWrite(MEMORY_VCC_CONTROL, HIGH);  // Assume HIGH = off

  digitalWrite(DEBUG_SPEED_CLK_ACTIVE_LED, HIGH);
  digitalWrite(HIGH_SPEED_CLK_ACTIVE_LED, HIGH);
  digitalWrite(RUNNING_PIN, HIGH);

  send_pc('I', "Entered EMULATE mode");
}
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
FASTRUN void loop() {
  static String serial_buffer;
  static bool inside_command = false;

  if (Serial.available()) {
    char start = Serial.read();
    if (start != '<') return;

    // Read 4-character length field
    char len_buf[5] = {0};
    size_t len_read = Serial.readBytes(len_buf, 4);
    if (len_read != 4) {
      send_pc('U', "INVALID: length parse failed");
      return;
    }

    uint16_t payload_len = strtoul(len_buf, nullptr, 16);
    if (payload_len == 0 || payload_len > 1024) {
      send_pc('U', "INVALID: bad length " + String(payload_len));
      return;
    }

    uint8_t buffer[1024];
    for (uint16_t i = 0; i < payload_len; ++i) {
      int ch = Serial.read();
      if (ch == -1) {
        send_pc('U', "TIMEOUT: only " + String(i) + " of " + String(payload_len) + " bytes received");
        return;
      }
      buffer[i] = (uint8_t)ch;
    }

    if (payload_len >= 5 &&
        buffer[0] == 'W' && buffer[1] == 'R' &&
        buffer[2] == 'I' && buffer[3] == 'T' &&
        buffer[4] == 'E') {
      handle_write_binary(buffer, payload_len);
    } else {
      // Treat as ASCII command
      String ascii_cmd = "";
      for (int i = 0; i < payload_len; ++i) ascii_cmd += (char)buffer[i];
      ascii_cmd.trim();
      handle_command(ascii_cmd);
    }

  }

  static uint32_t last_addr = 0xFFFFFFFF;

  if (state == EMULATING) {
    uint32_t addr = 0;
    for (uint8_t i = 0; i < config.address_count; ++i) {
      addr |= digitalReadFast(config.address_pins[i]) << i;
    }
  
    if (addr != last_addr) {
      last_addr = addr;
  
      // Direct lookup without bounds check — safe as max address is (1 << address_count)
      uint8_t value = psram_buffer[addr];
  
      for (uint8_t i = 0; i < config.data_count; ++i) {
        digitalWriteFast(config.data_pins[i], (value >> i) & 1);
      }
    }
  }
  

}

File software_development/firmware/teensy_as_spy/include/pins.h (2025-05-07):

#define GPIO1_3 0  
#define GPIO1_2 1  
#define GPIO2_10 6
#define GPIO2_16 8
#define GPIO2_11 9
#define GPIO2_0 10
#define GPIO2_2 11
#define GPIO2_1 12
#define GPIO1_12 24 
#define GPIO1_13 25 
#define GPIO1_30 26 
#define GPIO1_31 27 
#define GPIO2_12 32 
#define GPIO1_25 23 
#define GPIO1_24 22
#define GPIO1_27 21 
#define GPIO1_26 20 
#define GPIO1_16 19 
#define GPIO1_17 18
#define GPIO1_22 17
#define GPIO1_23 16
#define GPIO1_19 15
#define GPIO1_18 14
#define GPIO2_3 13
#define GPIO1_21 41
#define GPIO1_20 40
#define GPIO1_29 39
#define GPIO1_28 38
#define GPIO2_28 35
#define GPIO2_29 34

#define D1 GPIO1_2
#define D2 GPIO2_28
#define D3 GPIO2_29
#define D4 GPIO2_16
#define D5 GPIO2_12
#define D6 GPIO2_11
#define D7 GPIO2_10
#define D8 GPIO2_3

#define A0 GPIO1_3
#define A1 GPIO1_12
#define A2 GPIO1_13
#define A3 GPIO1_16
#define A4 GPIO1_17
#define A5 GPIO1_18
#define A6 GPIO1_19
#define A7 GPIO1_20
#define A8 GPIO1_21
#define A9 GPIO1_22
#define A10 GPIO1_23
#define A11 GPIO1_24
#define A12 GPIO1_25
#define A13 GPIO1_26
#define A14 GPIO1_27
#define A15_VCC GPIO1_28
#define A16 GPIO1_29
#define A17_VCC GPIO1_30
#define A18 GPIO1_31

#define N_CE GPIO2_2
#define N_OE GPIO2_1
#define N_WE GPIO2_0

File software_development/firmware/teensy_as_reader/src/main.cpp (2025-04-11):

#include <Arduino.h>
#include "pins.h"

const unsigned int delay_us = 5; //125 spy faalt //6147  read write faalt, read is the culprit                                     // Add a delay prior to/after a writing and other operations to ensure correct behavior (in micro-seconds)


const int nr_of_pins = 28;                                                   
const int nr_of_CS = 1;                                                     
const int nr_of_A    = 13;                                                     
const int nr_of_IO   = 8;    

uint16_t address_space = pow(2, nr_of_A);

bool OE_active_high = false;                                                    
bool WE_active_high = false;                                                   
bool CS_active_high = false;                                         

int mapped_CS_pins[nr_of_CS] = {N_CE};
int mapped_A_pins[nr_of_A] = {A0, A1, A2, A3, A4, A5, A6, A7, A8, A9, A10, A11, A12};
int mapped_IO_pins[nr_of_IO] = {D1, D2, D3, D4, D5, D6, D7, D8};
int mapped_OE_pins[1] = {N_OE};
int mapped_WE_pins[1] = {N_WE}; 


void set_pinmodes();
void read_all();
void fill_all();
void enable_output(bool OE_active);
void write_enable(bool WE_active);
void chip_enable(bool CS_active);
byte read_byte(int address);
void write_byte(int address, byte data);
void set_address(int address);
void PrintHex16(uint16_t* data, uint8_t length);
void printBinary(byte val);
void delay_cycles(uint32_t cycles);


void setup() {
  Serial.begin(115200);
  set_pinmodes();

  chip_enable(1);
  enable_output(0);                                                     // Do not enable reading
  write_enable(0);  

  delay(15);
  write_byte(2730, 85);
  delay(15);
  write_byte(5461, 170);
  delay(15);


  // 55 01010101
  // 8D 10001101
  // 85 10000101
  // E4 11100100

//   #define T_GPIO2_28 35 gpio 7
// #define T_GPIO2_29 34

 //53 65 45 4e
 write_byte(1, 0x53); // 01010011 // 55 01010101 /2 3  D8 staat op D2, D7 staat op D3, D6 staat op D4, D4 staat op D6, D3 staat op D8, D2 staat op D7 876432 234687
 delay(15);
 write_byte(2, 0x56); // 01100101 // 8D 10001101 /876432
 delay(15);
 write_byte(3, 0x45); // 01000101 // 85 10000101 /234687
 delay(15);
 write_byte(4, 0x4e); // 01001110 // E4 11100100
 delay(15);


}

// byte counter = 0;
// void loop() {
//   counter++;
//   write_byte(1123, counter);
//   delay(7);
//   byte data = read_byte(1123);
//   if(data != counter){
//       Serial.println("BAD READ");
//       printBinary(counter);
//       printBinary(data);
//       Serial.print("Diff:    ");
//       printBinary(counter ^ data); // XOR to highlight differences
//       delay(1000);
//   }

// }

int delay_between = 0;
void loop() {
    //53 65 45 4e
  write_byte(1, 0x53);
  // delay(delay_between);
  write_byte(2, 0x56);
  // delay(delay_between);
  write_byte(3, 0x45);
  // delay(delay_between);
  write_byte(4, 0x4e);
  // delay(delay_between);

  byte data = read_byte(1);
  //printBinary(data);
  // delay(delay_between);
  data = read_byte(2);
  //printBinary(data);
  // delay(delay_between);
  data = read_byte(3);
  //printBinary(data);
  // delay(delay_between);
  data = read_byte(4);
  //printBinary(data);

  // byte data = read_byte(12);
  // delay(10);
  // data = read_byte(5461);
  // delay(10);
  // data = read_byte(2730);

  // delay(delay_between);
  
  // printBinary(data);

  // if(data != 85){
  //     Serial.println("BAD READ");
  //     printBinary(data);
  //     delay(1000);
  // }

  // delay(10);

  // data = read_byte(5461);
  // // // printBinary(data);

  // // if(data != 170){
  // //     Serial.println("BAD READ");
  // //     printBinary(data);
  // //     delay(1000);
  // // }
  // delay(10);
}

void printBinary(byte val) {
  Serial.println(val, HEX);
  for (int i = 7; i >= 0; i--) {
    Serial.print(bitRead(val, i)); // Print each bit from MSB to LSB
  }
  Serial.println();
}

void read_all(){
  for (uint16_t address = 0; address <= address_space; address++) {
    if (address % 100 == 0 || address == address_space) {
      PrintHex16(&address, 1);
      Serial.print(" / ");
      PrintHex16(&address_space, 1);
      
      int percent = (100 * address) / address_space;
      Serial.println(" (" + String(percent) + "%)");
    }

    if (address == address_space) break;                                // The final index was increased by 1 and this line was added to show 100% completion
    
    byte data = read_byte(address);
    Serial.println(data);
  }
}

void fill_all(){
    for (int address = 0; address < address_space; address++) {
      write_byte(address, address);
    }
}


void set_pinmodes() {
  
  pinMode(mapped_OE_pins[0], OUTPUT);
  pinMode(mapped_WE_pins[0], OUTPUT);
  for (int i = 0; i < nr_of_CS; i++) {
    pinMode(mapped_CS_pins[i], OUTPUT);   
  } 

  enable_output(0);                                                     // Disable write enable pin
  write_enable(0);                                                      // Disable output enable pin
  chip_enable(0);                                                       // Disable chip select pins
  

  
  for (int i = 0; i < nr_of_A; i++) {
    pinMode(mapped_A_pins[i], OUTPUT);
    digitalWriteFast(mapped_A_pins[i], LOW);
  }

  for (int i = 0; i < nr_of_IO; i++) {
    pinMode(mapped_IO_pins[i], INPUT);
  }
}

void enable_output(bool OE_active) {
  digitalWriteFast(mapped_OE_pins[0], (OE_active_high ? OE_active : !OE_active));
}

void write_enable(bool WE_active) {
  digitalWriteFast(mapped_WE_pins[0], (WE_active_high ? WE_active : !WE_active));
}

void chip_enable(bool CS_active) {
  for (int i = 0; i < nr_of_CS; i++) {
    digitalWriteFast(mapped_CS_pins[i], (CS_active_high ? CS_active : !CS_active));     
  }
}
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

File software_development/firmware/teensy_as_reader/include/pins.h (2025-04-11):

#define T_GPIO1_3 0  
#define T_GPIO1_2 1  
#define T_GPIO2_10 6
#define T_GPIO2_16 8
#define T_GPIO2_11 9
#define T_GPIO2_0 10
#define T_GPIO2_2 11
#define T_GPIO2_1 12
#define T_GPIO1_12 24 
#define T_GPIO1_13 25 
#define T_GPIO1_30 26 
#define T_GPIO1_31 27 
#define T_GPIO2_12 32 
#define T_GPIO1_25 23 
#define T_GPIO1_24 22
#define T_GPIO1_27 21 
#define T_GPIO1_26 20 
#define T_GPIO1_16 19 
#define T_GPIO1_17 18
#define T_GPIO1_22 17
#define T_GPIO1_23 16
#define T_GPIO1_19 15
#define T_GPIO1_18 14
#define T_GPIO2_3 13
#define T_GPIO1_21 41
#define T_GPIO1_20 40
#define T_GPIO1_29 39
#define T_GPIO1_28 38
#define T_GPIO2_28 35
#define T_GPIO2_29 34

#define D1 T_GPIO1_2 //1
#define D2 T_GPIO2_28 //35
#define D3 T_GPIO2_29 // 34
#define D4 T_GPIO2_16 // 8
#define D5 T_GPIO2_12 // 32
#define D6 T_GPIO2_11 // 9
#define D7 T_GPIO2_10 // 6
#define D8 T_GPIO2_3 //13

#define A0 T_GPIO1_3
#define A1 T_GPIO1_12
#define A2 T_GPIO1_13
#define A3 T_GPIO1_16
#define A4 T_GPIO1_17
#define A5 T_GPIO1_18
#define A6 T_GPIO1_19
#define A7 T_GPIO1_20
#define A8 T_GPIO1_21
#define A9 T_GPIO1_22
#define A10 T_GPIO1_23
#define A11 T_GPIO1_24
#define A12 T_GPIO1_25
#define A13 T_GPIO1_26
#define A14 T_GPIO1_27
#define A15_VCC T_GPIO1_28
#define A16 T_GPIO1_29
#define A17_VCC T_GPIO1_30
#define A18 T_GPIO1_31

#define N_CE T_GPIO2_2
#define N_OE T_GPIO2_1
#define N_WE T_GPIO2_0
